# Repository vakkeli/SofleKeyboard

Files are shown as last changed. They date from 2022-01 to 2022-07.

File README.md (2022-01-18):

# Sofle Keyboard Vakkeli fork

Own version off the great keyboard. Added 7th column to better support ISO and Nordic layout. Will be updating this readme. PCB is in prototype production at this point. Hopefully adding 3D printed plates, case and models for them.

# Original Sofle Keyboard

Sofle is 6×4+5 keys column-staggered split keyboard with encoder support. Based on [Lily58](https://github.com/kata0510/Lily58), [Corne](https://github.com/foostan/crkbd) and [Helix](https://github.com/MakotoKurauchi/helix) keyboards.

**[For more information and documentation visit https://josefadamcik.github.io/SofleKeyboard/](https://josefadamcik.github.io/SofleKeyboard/)**

SofleKeyboard was created by [Josef Adamcik](https://josef-adamcik.cz/). The motivation and process is covered in following blog-post: [Let me introduce you SofleKeyboard - a split keyboard based on Lily58 and Crkbd](https://josef-adamcik.cz/electronics/let-me-introduce-you-sofle-keyboard-split-keyboard-based-on-lily58.html)

Sofle RGB was contributed by [Dane Evans](https://github.com/DaneEvans).

## Firmware

Sofle uses [QMK firmware](https://qmk.fm/)

## Default layout

Default layout for SofleKeyboard

## Images of keyboard

SofleKeyboard

SofleKeyboard Choc

SofleKeyboard PCB

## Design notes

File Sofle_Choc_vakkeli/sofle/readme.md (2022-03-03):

# Sofle Keyboard

SofleKeyboard version 1

Sofle is 6×4+5 keys column-staggered split keyboard. Based on Lily58, Corne and Helix keyboards.

More details about the keyboard on my blog: [Let me introduce you SofleKeyboard - a split keyboard based on Lily58 and Crkbd](https://josef-adamcik.cz/electronics/let-me-introduce-you-sofle-keyboard-split-keyboard-based-on-lily58.html)

The current (temporary) build guide and a build log is available here: [SofleKeyboard build log/guide](https://josef-adamcik.cz/electronics/soflekeyboard-build-log-and-build-guide.html)

* Keyboard Maintainer: [Josef Adamcik](https://josef-adamcik.cz) [Twitter:@josefadamcik](https://twitter.com/josefadamcik)  
* Hardware Supported: SofleKeyboard PCB, ProMicro  
* Hardware Availability: [PCB & Case Data](https://github.com/josefadamcik/SofleKeyboard)

Make example for this keyboard (after setting up your build environment):

    make sofle:default

Flash the default keymap: 

    make sofle:default:avrdude

Press reset button on he keyboard when asked.

Disconnect the first half, connect the second one and repeat the process.

See the [build environment setup](https://docs.qmk.fm/#/getting_started_build_tools) and the [make instructions](https://docs.qmk.fm/#/getting_started_make_guide) for more information. Brand new to QMK? Start with our [Complete Newbs Guide](https://docs.qmk.fm/#/newbs).

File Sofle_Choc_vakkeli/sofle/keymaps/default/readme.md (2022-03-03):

SofleKeyboard default keymap
SofleKeyboard adjust layer

# Default keymap for Sofle Keyboard

Layout in [Keyboard Layout Editor](http://www.keyboard-layout-editor.com/#/gists/76efb423a46cbbea75465cb468eef7ff) and [adjust layer](http://www.keyboard-layout-editor.com/#/gists/4bcf66f922cfd54da20ba04905d56bd4)

Features:

- Symmetric modifiers (CMD/Super, Alt/Opt, Ctrl, Shift)
- Various modes, can be switched (using Adjust layer and the selected one is stored in EEPROM.
- Modes for Qwerty and Colemak support
- Modes for Mac vs Linux/Win support -> different order of modifiers and different action shortcuts on the "UPPER" layer (the red one in the image). Designed to simplify transtions when switching between operating systems often.
- The OLED on master half shows selected mode and caps lock state and is rotated.
- Left encoder controls volume up/down/mute. Right encoder PGUP/PGDOWN.

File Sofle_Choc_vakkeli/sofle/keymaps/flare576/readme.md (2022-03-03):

Flare576 Keycaps
Flare576 Chord Guide

# Flare576's keymap for Sofle Keyboard

[Layout](http://www.keyboard-layout-editor.com/#/gists/fb8b42a6156458e20ca421a6f80cec48) and [Chord Mapping](http://www.keyboard-layout-editor.com/#/gists/884e3bc833cdf80fed9337ffee93a500) in Keyboard Layout Manager

Features:

- WASD -> ESDF Gaming layer
- Mouse/Arrow Keys Layer with **amazing** rates
- Tap/Hold keys for `=/+`/`SHIFT`, `TAB`/`ALT`
- Bracket layer with Fn Keys
- Right-hand primary OLED
  * Mode logo
  * Mode title
  * Luna WPM indicator
- Left-hand secondary OLED scrolling logo marquee
- Left encoder controls volume up/down/mute. Right encoder PGUP/PGDOWN/Home.

See [My Sofle Project](https://github.com/flare576/sofle) for more details

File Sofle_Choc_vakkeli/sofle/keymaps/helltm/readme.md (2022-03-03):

Luna - The QMK Keyboard Pet (https://www.youtube.com/watch?v=HgIQRazCAjo)

# Personal keymap for Sofle Keyboard rev1

Features:

- Modes for Qwerty and Games support. Games swaps enter and space to play FPS games and adds directional arrows.
- Modified Qwerty layout to allow usage without hidden layers (for the most).
- The OLED on master half shows selected OS, Layer and caps lock state.
- The secondary display shows a logo and the wpm counter.
- Left encoder controls arrow left/right. Right encoder arrow up/down.
- Holding shift changes the encoders to next/previous and volup/voldown respectively.
- Press the encoders to play/pause and mute.
- Smart Backspace (shift + backspace to delete)
- Single Layer button (press to Lower, shift + press to change mode)
- **Features Luna, your keyboard pet!**

#Luna, the keyboard pet

Features:
- Luna reacts to your wpm counter
    - under 10 wpm she sits
    - between 10 and 40 wpm she walks
    - over 40 wpm she runs
- She will move sneakily if you hold down Ctrl
- Will bark at people on the internet if you activate Caps Lock!
- Luna jumps every time you hit Space

Learn how to adopt a keyboard pet here
https://www.youtube.com/watch?v=HgIQRazCAjo

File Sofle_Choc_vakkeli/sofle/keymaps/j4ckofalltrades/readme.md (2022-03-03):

SofleKeyboard custom keymap

# Via-compatible custom keymap for Sofle

Modified version of default Via-compatible keymap with focus on adding a standard navigation cluster layer plus some
Vim-inspired features e.g. soft escape (Esc when held, Ctrl when tapped), using 'h', 'j', 'k', 'l' as arrow keys.

## Layout

View in [Keyboard Layout Editor](http://www.keyboard-layout-editor.com/#/gists/a1f6519e723ad81ca151741b53a28b80)

## Features

- Via support
- Mode for soft escape (`Esc` when tapped, `Ctrl` when held) 
- Vim-style navigation (`h` `j` `k` `l` as arrow keys)
- Mode for standard navigation cluster
- Toggling between layers when encoders are pressed
- Left encoder controls `VOLUP`/`VOLDOWN`. Right encoder `PGUP`/`PGDN`.

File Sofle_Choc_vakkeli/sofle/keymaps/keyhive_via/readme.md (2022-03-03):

# Only compatible with sofle/keyhive firmware which adds an extra column of keys for encoder mapping.

SofleKeyboard version 2.1 RGB Keyhive

# Configuring VIA / Vial App

This firmware will not auto-recognize until [PR #1060](https://github.com/the-via/keyboards/pull/1060) is accepted to the VIA keyboard database. For now you must install the new layout:

1. Download [keyhive_sofle_rgb.json](https://raw.githubusercontent.com/the-via/keyboards/48372baae5ab451d752988121fa4f1dd47b2c1ce/src/sofle/keyhive_sofle_rgb.json).
2. In the VIA app, select `File > Import Keymap` from the menu.
3. Open the file you just downloaded.

**You'll have to do this every time you use VIA or Vial until the PR is accepted.**

# Using with VIA
* The default layouts should be loaded automatically.
* Layouts can be backed up in VIA in the SAVE+LOAD section.
* It is a good idea to Save Current Layout after you decide on your mapping.

# Custom Features:

### Rotary Encoder and VIA Features:
* Fully remappable. Left encoder controls volume up/down/mute. Right encoder PGUP/PGDOWN.
* Allows for live remapping of per-layer rotary encoder functions in VIA.
* VIA support with **keyhive_via** keymap.

# Compiling

Make example for this keyboard (after setting up your build environment):

    make sofle/keyhive:keyhive_via

## Flashing

Flash using the correct command below (or use QMK Toolbox). These commands can be mixed if, for example, you have an Elite C on the left and a pro micro on the right.

Press reset button on the keyboard when asked.

Disconnect the first half, connect the second one and repeat the process.

    # for Pro Micro-based builds
    make sofle/keyhive:keyhive_via:avrdude-split-left
    make sofle/keyhive:keyhive_via:avrdude-split-right

    # for Elite C or DFU bootloader builds
    make sofle/keyhive:keyhive_via:dfu-split-left
    make sofle/keyhive:keyhive_via:dfu-split-right

See the [build environment setup](https://docs.qmk.fm/#/getting_started_build_tools) and the [make instructions](https://docs.qmk.fm/#/getting_started_make_guide) for more information. Brand new to QMK? Start with our [Complete Newbs Guide](https://docs.qmk.fm/#/newbs).

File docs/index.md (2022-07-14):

---
layout: default
---

SofleKeyboard

Sofle is 6×4+5 keys column-staggered split keyboard with encoder support. Based on [Lily58](https://github.com/kata0510/Lily58), [Corne](https://github.com/foostan/crkbd) and [Helix](https://github.com/MakotoKurauchi/helix) keyboards. SofleKeyboard version 1 and 2 were created by [Josef Adamcik](https://josef-adamcik.cz/). Sofle RGB was contributed by [Dane Evans](https://github.com/DaneEvans).

[Build guide is available here]({{ baseurl }}/SofleKeyboard/build_guide.html).

If you are interested in building the board and don't want to bother with KiCad, the gerber files are available in [releases](https://github.com/josefadamcik/SofleKeyboard/releases) or as [zip files in github repository](https://github.com/josefadamcik/SofleKeyboard/tree/master/Gerbers)

## Versions 

### Version 1

SofleKeyboard v1

The first version is mostly a modification of Lilly58 Pro. Motivation and detailed information is covered in the following blog-post: [Let me introduce you SofleKeyboard - a split keyboard based on Lily58 and Crkbd](https://josef-adamcik.cz/electronics/let-me-introduce-you-sofle-keyboard-split-keyboard-based-on-lily58.html). 

There were several group buys and PCBs or kits were available through several sellers. 

[Build guide is available here]({{ baseurl }}/SofleKeyboard/build_guide.html).

### Version 2

SofleKeyboard v1 and v2

Changes a stagger of columns and position of the bottom row a bit. The whole board was rerouted, shape changed slightly. Below version 1 in yellow, version 2 in blue.

SofleKeyboard v1/v2 layout comparison

A few experiments were made:

- A differently mounted micro-controllers with staggered holes.
- Placement of components around pro micros were also changed.
- Support for low profile Kailh Choc switches was dropped.

Those changes were experiments and I have been planning to reverse them and/or tweak them more. Details in the following blog-post: [Sofle Keyboard evolution: slow and not really steady](https://josef-adamcik.cz/electronics/soflekeyboard-evolving.html). 

Since the development was not moving forward for several months and there were many people interested in the new layouts (including group buys and vendors willing to sell kits), it was decided to release it in the current state as the version 2. Only one obvious problem was fixed (a too small size of a cut-out for encoder in the top plate).

[Build guide is available here]({{ baseurl }}/SofleKeyboard/build_guide.html).

### RGB

**&#9888; If you bought Sofle RGB from Keyhive, see the disclamer below, please.**

SofleKeyboard RGB

Sofle RGB was contributed by [Dane Evans](https://github.com/DaneEvans).

The Sofle RGB is a copy of the Sofle v2 with the addition of up to 36 RGB LEDs per side. If you are just looking to try out that layout, and are using the cherry sockets only, then this will work for you. 

The original pro-micro pinout was rolled back and routing was redone.

The OLED placement and OLED cover plate holes have not changed, and a plate has been designed. 

[Build guide is available here]({{ baseurl }}/SofleKeyboard/build_guide_rgb.html).

###	&#9888; Keyhive RGB

One keyboard vendor - Keyhive - is selling their own fork of Sofle RGB. This version is **modified** in way that makes it **incompatible** with the firmware for the official designs. You have to use the firmware provided by the vendor and build guide provided by them as well. Please, don't report problems with the desing and or firmware to this repository. Their modification is not part of the repository and therefore we cannot fix the problems or help you. Contact the vendor instead. In the end, you are their client.

[Build guide is available here]({{ baseurl }}/SofleKeyboard/build_guide_rgb.html).

### Choc

Sofle Choc

The Sofle Choc is a variation of the Sofle with:

   - low-profile, Kailh Choc switches
   - hotswap sockets
   - per-key RGB
   - thin, 15mm from desktop to top of keycaps
   - Sofle RGB switch layout with pinky stagger in between v1 and v2

The Sofle Choc was contributed by [Brian Low](https://github.com/brianlow) and based on the excellent Sofle RGB by [Dane Evans](https://github.com/DaneEvans).

[Build guide is available here]({{ baseurl }}/SofleKeyboard/build_guide_choc.html).

## Modifications

- [Sofle V2 with RJ12 instead of TRRS](https://gitlab.com/LayeredRx/Sofle_V2_Rj12/) by Layered RX

## License

- Hardware source files are licensed under MIT license.
- The documentation (both on [josefadamcik.github.io/SofleKeyboard/](https://josefadamcik.github.io/SofleKeyboard/) and [https://josef-adamcik.cz/](https://josef-adamcik.cz/)) is licensed under [Creative Commons Attribution 4.0 International (CC BY 4.0)](https://creativecommons.org/licenses/by/4.0/) license. This includes all photos and images in this repository and on the website.
- Firmware is part of QMK firmware and has the same licence (GPL v2)

## Firmware 

Sofle uses [QMK firmware](https://qmk.fm/)

See the [build environment setup](https://docs.qmk.fm/#/getting_started_build_tools) and the [make instructions](https://docs.qmk.fm/#/getting_started_make_guide) for more information. Brand new to QMK? Start with our [Complete Newbs Guide](https://docs.qmk.fm/#/newbs).

Make example for this keyboard (after setting up your build environment):

    make sofle:default

Flash the default keymap: 

    make sofle:default:avrdude

Press reset button on he keyboard when asked.

Disconnect the first half, connect the second one and repeat the process.

You can also use [QMK configurator](https://config.qmk.fm/#/sofle/rev1/LAYOUT) but beware, it does not support rotary encoders yet.

## Default layout 

Default layout for SofleKeyboard

## Gallery

Version 1 at the top, version 2 at the bottom:

SofleKeyboard

### Version 1

SofleKeyboard

SofleKeyboard Choc

SofleKeyboard PCB

### RGB

SofleRGBKeyboard

SofleRGBKeyboard

SofleRGBKeyboard PCB

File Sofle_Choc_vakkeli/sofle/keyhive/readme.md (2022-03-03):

# Keyhive Sofle Keyboard

SofleKeyboard version 2.1 RGB Keyhive

Sofle is 6×4+5 keys column-staggered split keyboard. Based on Lily58, Corne and Helix keyboards.

For details about the keyboard design, refer to Josef's blog: [Sofle Keyboard - a split keyboard based on Lily58 and Crkbd](https://josef-adamcik.cz/electronics/let-me-introduce-you-sofle-keyboard-split-keyboard-based-on-lily58.html)

Build guide: [Keyhive Sofle RGB build guide](https://github.com/keyhive/build_guides/blob/master/docs/keyboards/sofle-rgb.md)

* Keyboard Maintainer: [Winder](https://github.com/winder)
* Hardware Supported: Keyhive Sofle RGB, ProMicro / Elite-C
* Hardware Availability: [Keyhive](https://keyhive.xyz/shop/sofle)

### Acknowledgements

* Solartempest - the image on this page and most of the code is either copied directly or inspired by their fork. [Solartempest's fork.](https://github.com/solartempest/qmk_firmware/tree/master/keyboards/solartempest/sofle).
* [Keyhive fork](https://github.com/keyhive/qmk_firmware) defined all of the board settings.

# Supported Keymaps

The keyhive schematic has been slightly modified compared to the open source sofle and not all keymaps are compatible.

* **default**: Basic functionality, no rgb, no VIA.
* [keyhive_via](../keymaps/keyhive_via/readme.md) - Includes rgblighting and special support for remapping encoders with VIA.
* **Other**: may work but backwards compatibility is not guaranteed or tested.

# VIA Support
As of 1.3.1, the VIA tool does not support Keyhive/Sofle V2 out of the box.
See [keyhive_via](../keymaps/keyhive_via/readme.md) for details about configuring and using VIA.

# Compiling

Make example for this keyboard (after setting up your build environment):

    make sofle/keyhive:default

## Flashing

Flash using the correct command below (or use QMK Toolbox). These commands can be mixed if, for example, you have an Elite C on the left and a pro micro on the right.

Press reset button on the keyboard when asked.

Disconnect the first half, connect the second one and repeat the process.

    # for Pro Micro-based builds
    make sofle/keyhive:default:avrdude-split-left
    make sofle/keyhive:default:avrdude-split-right

    # for Elite C or DFU bootloader builds
    make sofle/keyhive:default:dfu-split-left
    make sofle/keyhive:default:dfu-split-right

See the [build environment setup](https://docs.qmk.fm/#/getting_started_build_tools) and the [make instructions](https://docs.qmk.fm/#/getting_started_make_guide) for more information. Brand new to QMK? Start with our [Complete Newbs Guide](https://docs.qmk.fm/#/newbs).

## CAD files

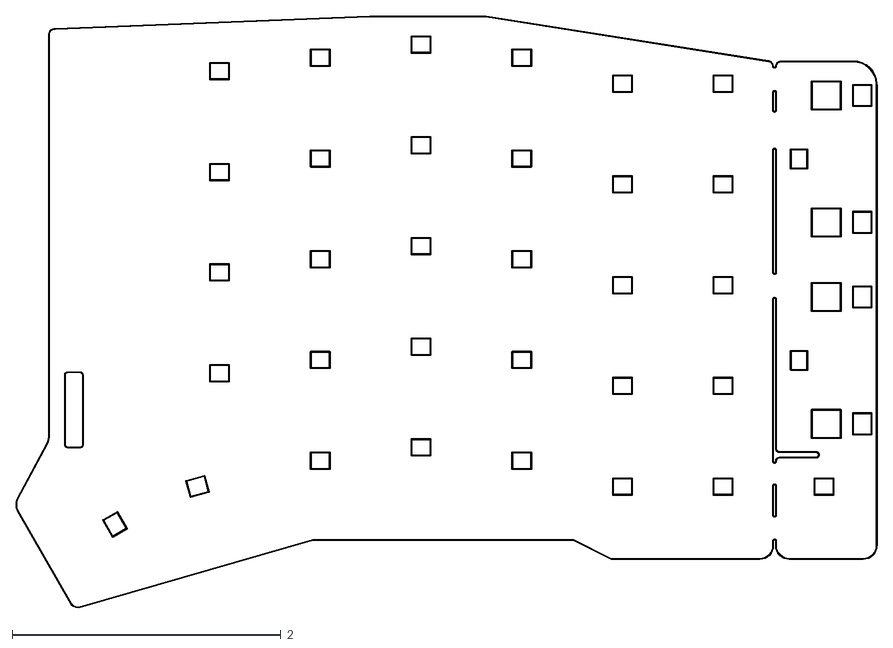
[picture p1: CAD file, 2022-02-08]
Sofle_Choc_vakkeli/gerber/SofleKeyboard-Edge_Cuts.dxf
6.41 x 4.40

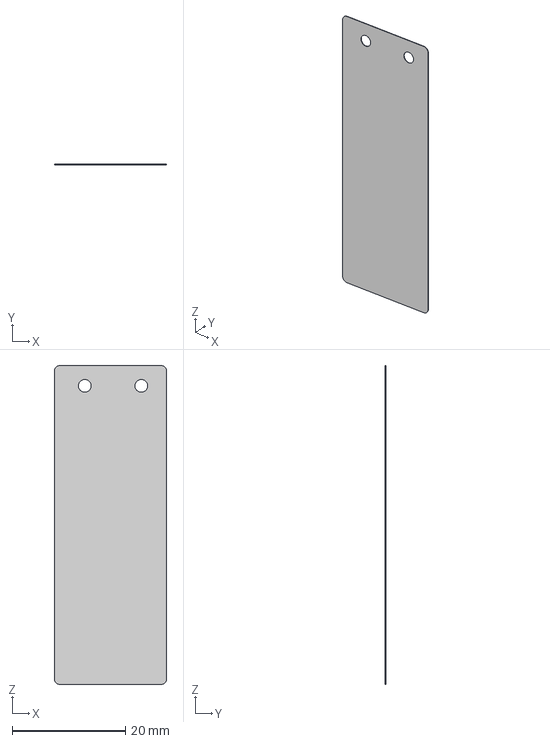
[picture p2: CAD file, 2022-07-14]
Sofle_v2/Case/sofle_v2_oled_cover_0.1.step
19.9 x 0.1 x 56.5 mm

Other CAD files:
Sofle_Choc_vakkeli/gerber/SofleKeyboard-B_Mask.dxf
Sofle_Choc_vakkeli/gerber/SofleKeyboard-B_SilkS.dxf
Sofle_Choc_vakkeli/gerber/SofleKeyboard-F_Mask.dxf
Sofle_Choc_vakkeli/gerber/SofleKeyboard-F_SilkS.dxf
Sofle_v2/Case/sofle_v2_oled_cover_0.1.dxf
Sofle_v2/Case/sofle_v2_oled_cover_0.1.f3d

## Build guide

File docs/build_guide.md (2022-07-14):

---
layout: default
title: Sofle Keyboard - build guide (v1/v2)
---

This guide suits both version **V1** and **V2** of the standard (**non-RGB**) Sofle Keyboard. Most of the photos are for v1 and the differences are explained in the text as needed.

The **RGB** version has [dedicated build guide][rgbbuildguide].

The **Choc** version has [dedicated build guide][chocbuildguide].

If you don't have all the necessary parts, please read about [how to source the parts][sourcing].

## Bill of materials

The following is needed to build the keyboard. You can find [links for the most of the components in the sourcing parts section][sourcing].

SofleKeyboard parts

- **2 PCBs** (see [sourcing][sourcing])
- **2 top plates**, **2 bottom plates** for a sandvich-case build. (see [sourcing][sourcing])
- **58 keyboard switch sockets by Kailh**. The PCB supports either sockets for traditional MX switches or sockets for Kailh Choc switches. **Note that version 2 supports only MX.** They are available on Aliexpress, KBDFans and others. 
- **58 keyboard switches** of your preference, either MX or [Kailh Choc][choc]. Just make sure you have matching sockets for them. **Note that version 2 supports only MX**.
- **58 keycaps**. You can use either all in `1u` size but it looks nicer with two `1.5u` for the thumb keys.
- **58 diodes  1N4148W**. They are surface mount diodes in SOD123 package.
- **2 TRRS connectors**. The same type which is used for Corne, Lily58 etc. Technically even TRS should work[^1] if you stick to (default) serial communication. 
- **2 tactile buttons** through-hole, 2 pins. Technically optional: you can use metal tweezers whenever you need to reset the microcontroller. There's also a reset key on default layout so as long as you have firmware flashed and working you shouldn't need reset button on the board. 
- **1 TRRS cable**. TRS should work[^1] if you stick with Serial. 
- **10 (+4) M2 spacers**. 10 are going to hold the bottom and the top together. Their height depends on which switches you use. A build guide Lily58 Pro suggests `4mm` for Choc and `7mm` for MX. I was not able to get `7mm`, but `6mm` worked well for me with MX switches. I used brass ones but you can also buy nicer from anodised aluminium. Another 4 would be needed to hold transparent OLED cover but even though there are mounting holes in the PCB.
- **20 (+8) M2 screws**. 20 are going to hold the boards together (via spacers). I used some I had in my stock so I am not going to tell you exact length. But they need to be long enough to fix a `1.6mm` thick PCB to the spacer and short enough so two of them can fit in one spacer (might be trickier with 4mm spacers for Choc switches)
- **8 - 10 adhesive rubber feet**. They are really important, trust me.
- **2 ssd1306 128x32 OLED display module**. Very common everywhere. 
- **2 OLED covers** Optional. OLED cover should be cut from transparent acrylic. Source file for [version 1 is avalalble in the repostiory](https://github.com/josefadamcik/SofleKeyboard/tree/master/Sofle_v1/Case). There is no OLED cover for version 2 available yet.
- **2 Rotary encoders EC11**, optional. So far I have used only one but 2 are supported. If you are not sure take EC11E. Some other variants (EC11K) may have some additional plastic pins for and require mounting holes for them (which are not included on the PCB).
- **A matching knob** for each encoder. 
- **2 Pro Micro**board or clone. With 2x12 pins and ATmega32U4 microcontroller. Just make sure you **don't** buy something like Arduino Micro (a different pinout) or Arduino Mini (different microcontroller). You could also use Elite-C which basically Pro Micro with USB-C.
- **4x12 pin header (and optionally socket)** for Pro Micros. There are several ways how to mount Pro Micros to the board. Either the male PIN headers you most likely got with the board from the supplier could be used to solder it directly to the board. Build guides for Helix, Corne and Lily58 suggest [those spring pin headers][springpinheader] which are very compact and give you non-permanent connection (you can remove or replace Pro Micros). Another possible approach [is described at splitkb.com][promicrosocketing].
- **2x4 pin header (and optionally socket)** for OLEDs. I have used the most common 1x4 female pin sockets which are quite tall but they also fit the height of ProMicro with the sockets I have used. Unfortunately, the pin headers on my OLED modules (again those very common square male headers you would get with the modules) are loose in the sockets. It works but it's fiddly. I'll have to find a better solution.
- **Micro USB Cable** to connect the keyboard to a computer.

SofleKeyboard parts 2

That's it. There are no RGB LEDs on the board. But if you really need underglow it is be possible to connect an RGB LED strip since there are 3 pads (VCC, GND and data) on the board. You would need to add support to the firmware on your own.

## Tools and materials

- soldering iron
- solder 
- good tweezers
- masking tape
- isopropyl-alcohol for cleaning 
- screwdriver

## Warnings and disclaimers

- Think twice, solder once. Desoldering is frustrating and it's easy to mess up things.
- Don't connect or disconnect the TRRS cable when the keyboard is powered. It may short out. Always disconnect the USB cable first.
- Be gentle with the USB on your microcontroller. They are easy to break.
- Keep in mind that this is a prototype of a DIY keyboard. It's not a polished product.

## Steps

### Prepare

Step 1

Both sides of the keyboard ready. The front sides marked by pieces of tape in order to remember which side is which.

### Components on the backside 

Step 2

Starting with the diodes. They belong to the backside of the PCB. Make sure you have orientation right - they are all oriented to the same side. The end with the thin line is Cathode (-) and it should go in the direction of the "arrow" symbol on the PCB.

Step 3

Sockets for switches belong again on the back side, the same side as diodes. Make sure they are flush with PCB. Watch the markings on the silkscreen which show the correct orientation.

### Components on the front side

Step 4

Button and TRRS sockets belong to the top. Use a piece of tape to fix them and apply solder from the bottom side.

Step 5

This is how the right half should look from the top.

### Pro Micro and displays

Step 6

Bridge 4 jumper pads on the top side. They are necessary for OLED support and if you don't socket you Pro Micro you will not be able to do it later.

Step 7

Prepare the Pro Micro. There are several ways how to do it. I have used rounded pin headers. A bit more information about [socketing of Pro Micro is on the sourcing parts page][sourcing]. 

**Keep in mind the orientation**: 

Pro micro orienation

Version 1: the Pro Micro board should be mounted "bottom-up". Its clean side should be at the top, visible. The side with chips and other electronics should be at the bottom facing the main PCB. 

Version 2: The left side as for version 1. The right half has the pro micro mounted up-side up so it's mounted differently on each half. 

Step 8

And corresponding sockets (if used) on the front side of the board. Version 1: Make sure you insert them into the holes which are marked by the rectangles. Version 2: there's only one option so it is straightforward.

Step 9

Add socket for OLED display. Keep in mind height of your Pro Micro which may be different based on if/which socket's you have used for Pro Micro. Check everything before soldering.

Step 10

This is how the backside (bottom) should look at this stage.

### First test

Step 11

Now it is already possible to connect the ProMicro and OLED display to the board, flash the firmware and check if all keys work using a piece of wire or tweezers.

### Rotary encoders

Step 12

Both halves assembled, a rotary encoder can be added on both, one or none. I have also cleaned flux residue from the back side using some isopropyl alcohol, cotton buds and paper towels.

### Keyboard switches and plates

Step 14

Snap first switches into corners.

Step 15

Mount the stand-offs to the top plate.

Step 16

Carefully snap the first switches to the sockets. Be careful so you don't bend their contacts. Add more.

Step 17

Until they are all in place.

Step 18

Double-check the bottom. You should see all the contacts in sockets.

Step 19

And mount the bottom plate.

Step 20

Completed half of the keyboard waiting for keycaps.

### Finishing touches

Step 21

Put at least 4 adhesive rubber feet in the corners so the keyboard is not moving when you type.

## Warnings and disclaimers

- Don't connect or disconnect the TRRS cable when the keyboard is powered. It may short out. Always disconnect the USB cable first.
- Be gentle with micro USB ports on your microcontrollers. They are easy to break.
- Keep in mind that this is a prototype of a DIY keyboard. It's not a polished product.

## Firmware and programming

Sofle keyboard uses [QMK Firmware][qmk_firmware] and support for the board is part of the main QMK repository. There's also a basic support in [QMK Configurator][qmk_configurator] but there's no default layout yet and encoders are not supported.

Suggested approach is to build the firmware yourself. You should be familiar with QMK and be able to make it work on your local environment. If not, please [follow the instructions in the documentation][qmkintro].

- Make sure your QMK environment [is setup][qmkintro].
- Make sure halves are not connected together with TRRS cable.
- Connect one half to USB, flash the firmware (always follow the actuall instructions in the QMK documentation! The command might look something like this: `qmk flash -kb sofle/rev1 -km default`). Use the reset button to reset the keyboard when you are asked to in console. 
- Connect the second half and flash it in the same way as the previous one.
- Disconnect the USB cable. Connect both halves together with TRRS cable.
- Connect USB cable to the **left** side[^2]. 
- Enjoy SofleKeyboard!

## Troubleshooting

### Elite-C v3.0

Elite-C v3.0 had problems when used with split boards (on both halves). Those are fixed in version 3.1. For v3.0 add `#define SPLIT_USB_DETECT` to `config.h` file. I don't have Elite-C so this is untested, but should work.

### Typing lag when used without OLED 

If you chose to not use OLED for both halves you should disable support for oled (set `OLED_DRIVER_ENABLE` to `no` in `keymaps/defualt/rules.mk`).

If you don't use OLED only on one half you are need to do **one** of the following to fix the lag:

- Solder pull-up resistors (4k7) to the PCB (R1, R2) without OLED.
- Use a workaround explained [in this issue][nooledlag].
- Stop using OLED completely and turn it off as described above.

## Modifications

### Inverted silkscreen

If you fancy an [inverted silkscreen there's a great guide available](https://github.com/josefadamcik/SofleKeyboard/issues/3#issuecomment-683192038).

## Links

- [Github with KiCad projects][soflegithub]
- [Layout in KeyboardLayout editor][soflelayout]
- [QMK Firmware][qmk_firmware]
- [QMK Configurator][qmk_configurator]

## Footnotes

[^1]: Serial is the default behaviour. If serial is used, you don't need TRRS cable (4 contacts, used for headphones with a microphone) but just TRS (stereo audio jack). 
[^2]: This can be changed, look for [setting handednesss][qmkhandedness] in QMK documentation.
[^3]: There was a design issue where the cutout for the encoder is big enough only for the base of the encoder but not for its legs. That is perfectly ok when you build the board with MX switches since the plate sits above the legs. But for low profile Kailh Choc switches there's no longer any gap between plates. If you have unfixed plate (the problem was fixed in v1.1.) and wish to use an encoder, you'll need to file off a bit of PCB material to get the legs of encoder through (see the guide above).

[layoutarticle]: <https://josef-adamcik.cz/electronics/in-search-of-the-best-custom-keyboard-layout.html> "In search of the best custom keyboard layout"
[introductionarticle]: <https://josef-adamcik.cz/electronics/let-me-introduce-you-sofle-keyboard-split-keyboard-based-on-lily58.html> "Let me introduce you SofleKeyboard - a split keyboard based on Lily58 and Crkbd"
[soflelayout]: http://www.keyboard-layout-editor.com/#/gists/76efb423a46cbbea75465cb468eef7ff "Sofle Keyboard layout at keyboard-layout-editor.com"
[soflegerber]: https://github.com/josefadamcik/SofleKeyboard/releases "SofleKeyboard - gerber files"
[qmk_firmware]: https://github.com/qmk/qmk_firmware/ "QMK firmware"
{:target="_blank"}
[qmk_configurator]: https://config.qmk.fm/#/sofle/rev1/LAYOUT "QMK configurator"
{:target="_blank"}
[springpinheader]: <https://yushakobo.jp/shop/a01mc-00/> "Spring pin headers - Japaneese"
{:target="_blank"}
[qmkprotonc]: https://qmk.fm/proton-c/ "QMK Proton-C"
{:target="_blank"}
[promicrosocketing]: <https://docs.splitkb.com/hc/en-us/articles/360011263059> "How do I socket a microcontroller? by splitkb.com"
{:target="_blank"}
[qmkintro]: <https://beta.docs.qmk.fm/tutorial/newbs_getting_started> "QMK getting started"
{:target="_blank"}
[qmkhandedness]: <https://docs.qmk.fm/#/feature_split_keyboard?id=setting-handedness> "QMK firmware - setting handedness"
{:target="_blank"}
[manufacturingproblems]: https://josef-adamcik.cz/electronics/corne-keyboard-build-log.html#manufacturing-at-jlcpcb---update-27112019 "Possible problems when manufacturing top plate for Corne"
[nooledlag]: https://github.com/qmk/qmk_firmware/issues/7522 "No OLED lag bug"
[soflegithub]: https://github.com/josefadamcik/SofleKeyboard "SofleKeyboard - KiCad project on Github.com"
[sourcing]: <{{ site.baseurl }}/sourcing_parts.html> "Sourcing parts"
[rgbbuildguide]: <{{ site.baseurl }}/build_guide_rgb.html> "Sofle RGB build guide"
[chocbuildguide]: <{{ site.baseurl }}/build_guide_choc.html> "Sofle Choc build guide"

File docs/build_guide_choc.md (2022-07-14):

---
layout: default
title: Sofle Keyboard - build guide (Choc)
---

Keyboard
Keyboard Side View

The Sofle Choc is a variation of the Sofle with:

   - low-profile, Kailh Choc switches
   - hotswap sockets
   - per-key RGB
   - thin, 15mm from desktop to top of keycaps
   - Sofle RGB switch layout with pinky stagger in between v1 and v2

This version supports [Kailh Choc v1 switches](https://deskthority.net/wiki/Kailh_PG1350_series). Kailh hotswap sockets are required. Per-key RGB is optional and uses the relativey easy to solder SK6812 MINI-E LEDs.

The top plates are not compatible with Sofle v1, v2 or RGB versions. There is no bottom plate to minimize thickness.

The Sofle Choc was designed by [Brian Low](https://github.com/brianlow) and based on the excellent Sofle RGB by [Dane Evans](https://github.com/DaneEvans) which was based on the original Sofle v2 by [Josef Adamčík](https://github.com/josefadamcik).

## Updated Build Guide and Kits

I am maintaining a newer version of the build guide and usually have kits available at:

[http://choc.brianlow.com](http://choc.brianlow.com)

## Bill of materials

The following is needed to build the keyboard:

- **2 PCBs**. Send the zip from `/Gerbers/Choc_v2/choc-v2-gerber-pcb.zip` to a PCB fabrication service. The PCB should be 1.6mm thick [though 1.2mm may be better](https://github.com/josefadamcik/SofleKeyboard/issues/136#issuecomment-1045965676). Otherwise I used JLCPCB's default settings only customizing the PCB color. See [sourcing][sourcing].

- **2 top plates**. Send the zip `/Gerbers/Choc_v2/choc-v2-gerber-top.zip` to a PCB fabrication service. The top plate holds the switches in place. The top plate should be 1.2mm thick. Otherwise I used JLCPCB's default settings only customizing the PCB color. See [sourcing][sourcing].

- **2 Pro Micro** boards or clones. 5v, 2x12 pins, ATmega32U4 microcontroller. **Don't** buy the Arduino Micro (a different pinout) or Arduino Mini (different microcontroller). You could also use Elite-C which basically Pro Micro with USB-C.

- **4x 12 pin headers (and optional sockets)** for Pro Micros. There are several ways to mount Pro Micros to the board. The male pin headers you most likely got with the board can be used to solder it directly to the board. This makes it hard to replace the board if it fails. The micro-USB connector is known to tear off. I socketed the Pro Micro using the diode legs approach [described at splitkb.com][promicrosocketing] with two 12-pin female headers. This is the option descibed in the build guide here. Lastly, [these spring pin headers][springpinheader] are used on similar keyboards and should give a compact, non-permanent connection but have been out of stock for a long time.

- **58 Kailh Choc keyboard switches**. Must be [Kailh Choc v1 switches (PG1350)](https://deskthority.net/wiki/Kailh_PG1350_series) of any color. The `PG` prefix is often omitted. **Don't** buy [Kailh Choc v2](https://deskthority.net/wiki/Kailh_PG1353_series), [Kailh Mini Choc](https://deskthority.net/wiki/Kailh_PG1232_series) or [Cherry MX](https://deskthority.net/wiki/Cherry_MX).

- **58 Kailh Choc keyboard switch sockets**. Sockets are specific to the PG1350 switch. The PCB requires sockets. Switches cannot be soldered directly to the board.

- **58 keycaps**. You can use either all in `1u` size but it looks nicer with two `1.5u` for the thumb keys.

- **58 diodes 1N4148W**. Surface mount diodes in SOD123 package. Pick any common variation. I used `1N4148WTR` (Digi-Key 1655-1360-1-ND).

- **2 TRRS connectors**. The same type which is used for Corne, Lily58 etc. Technically even TRS should work if you stick to the default serial communication.

- **2 buttons** momentary, tactile, through-hole, 2 pins, I used one for DIP switches, 3x6x4.3mm. Technically optional: you can use metal tweezers whenever you need to reset the microcontroller.

- **1 TRRS cable**. TRS should work if you stick with the default serial communications.

- **8 - 10 silicone bumpers**. Used for feet to keep the keyboard from moving

- **Micro USB Cable** to connect the keyboard to a computer.

Optional components:

- **OLED/s**
  - **2 SSD1306 128x32 OLED display module**. 4-pin, I2C, 0.91". Very common.
  - **2x 4 pin header (and optionally socket)** for OLEDs. These came pre-soldered to the OLED unit. You can solder the OLED directly to the board. Ideally use a socket so you can replace and/or get at the ProMicro underneath. I found 4 pin female headers with half height (~4mm) insulation worked well
  - **2 OLED covers** This should be compatible with the Sofle RGB cover but have not verified

- **Rotary encoders**
  - **2 Rotary encoders EC11**. If you are not sure take EC11E. Some other variants (EC11K) may have some additional plastic pins for and require mounting holes for them which are not included on the PCB. Perfer short shaft. I used encoders with 10mm, D-shaped shaft and 30 positions from AliExpress. I also tried a high quality Bourns encoder (PEC11 series) but found it required a bit too much effort to twist.
  - **2 matching knobs** for each encoder. Make sure the knob matches the encoder's shaft diameter, depth and shape.
  - **2 diodes 1N4148W** the encoder shafts are pushable and can be used as configurable keys.

- **LEDs**
  - **58 SK6812 MINI-E RGB LEDs**. The LED body 3.2x2.8x1.7mm and with legs is 5.8x2.8. Avoid the non-MINI-E version without the legs. Purchase extra as they are delicate. I ended up replacing 6 during my build.

- **Resistors**
  - **2x 4.7kOhm through hole resistors** These only needed if you want to use the less common I2C communication protocol between halves. They are installed in the R1/R2 spots. I have not tested an I2C setup. The firmware on this page uses serial communication and does not require the resistors.

Components that are common on other Sofle variants but are **not** used on this Softle Choc: bottom plate, M2 spacers and screws.

## Tools and materials

- soldering iron and solder
- no-clean flux makes soldering easier
- solder wick or desoldering pump to correct mistakes
- good tweezers
- flush cutters to trim diode legs when socketing the ProMicro
- masking, kapton or electrical tape
- isopropyl-alcohol for cleaning
- screwdriver
- 1.5mm hex key for the set screw on the encoder knob
- mulitmeter for troubleshooting

## Steps

### Prepare

Make sure you know which side you are working on, and don't make two left hand sides by mistake. Stick a piece of tape on the front side of both PCBs to help remember.

This guide is written in the order I like to install components.

We will start with the components on the back, shortest to tallest:
  - diodes
  - LEDs
  - switch sockets

Then install the components on the front:
  - OLED jumpers
  - ProMicro & socket
  - OLED & socket
  - reset switch
  - TRRS connector
  - encoder

The order of assemby does not matter **except** for these 3 components because they stack on top of one another:
  1. the four OLED jumpers
  2. the Pro Micro
  3. the OLED screen

The build guides for the Sofle and Sofle RGB have some good tips and photos. However there are differences so use this page as your primary reference. In particular, use the ProMicro orientation described on this page.

### Switch Sockets and Diodes

Switch sockets and diodes

These components are placed on the back of the PCB.

Diodes must be oriented with the white band in the direction of the "arrow" symbol on the PCB. I typically tin one pad, place the diode on, apply the soldering iron to the diode leg until it melts the solder underneath and sinks flush with the PCB. Then come back and solder the other leg.

The sockets are the largest and easiest to solder. They are installed on the back of the PCB facing up towards the front of the PCB. Make sure they are flush with the PCB. Heat the metal connector, apply solder and look for the solder to wick down to the PCB. You want a solid joint since this may take some mechanical strain from switch installation and removal.

### The LEDs

LED

LEDs are placed on the back of the PCB. The lens should point up through the PCB so they shine into the bottom of the switch. One leg will have a diagonal cut. This cut leg should be aligned with the triangular marking on the PCB.

To solder: tin one pad, place the LED and hold using tweezers, apply heat to the leg until the solder melts and the LED is flush with the board. Now the remaining legs can be soldered without the component moving. The LEDs are sensitive to heat. Let the LED cool between soldering each leg. Use the lowest heat needed for your solder.

The LEDs are wired in one long chain. If a LED is not working, replace the LED and the LED preceeding it. Sometimes just the output of a LED is damaged. The full chain does not need to be installed if you want to test a partially built board.

LED

### OLED Jumpers

OLED Jumpers

Now we move to the front of the PCB.

The jumpers in the photo should be bridged if using an OLED dispay. The jumpers may not be accessible later in the build depending on how the Pro Micro is attached. Bridge the jumpers on the top side of the board, the same side the ProMicro will be mounted on.

### Pro Micro

Pro Micro

The Pro Micro is installed on the top of the board, upside down and in the marked holes.

* Top of the board: this is the side of the PCB opposite the diodes, LEDs and switch sockets
* Upside down: both Pro Micro components should face the PCB with the mostly plain back facing out
* Marked holes: there are two sets of holes in the PCB, use the holes with the rectangular outline on the top of the board

Double-check your work here. This step is hard to reverse if a mistake is made.

To install a socketed Pro Micro using the diode leg approach [from splitkb.com][promicrosocketing]:

  1. Install the 12-pin female headers on the top of the board in the outlined through holes. Use some tape to temporarily tack them in place. Flip the board over onto a flat, hard surface. While soldering the first pins, push down on the PCB to ensure the headers are perpendicular and fully seated.

  2. Flip the board upright again. Optionally place some tape over the sockets to protect against fusing parts together. Place the Pro Micro upside down on top. Push diodes though the Pro Micro holes, through the tape and seated into the socket below.

  3. Solder the legs to the Pro Micro. Snip off the legs above the Pro Micro.

If you ever need to remove the Pro Micro: do it by gently prying the board up in small increments, working your way around the board. Avoid pressure on the USB connector. The diode leags are quite weak and will usually bend if you pull the Pro Micro off in one action.

### OLED

Install the OLED so it overhangs the Pro Micro. I added electrican's tape to the bottom of the OLED module where it might contact the Pro Micro.

If you are socketing the OLED, install the 4 pin, half height female header on the top of the PCB. Then push the OLED pins into the socket. You may need to trim the OLED pins so the insulation on the female and male headers mate and the OLED sits just above the Pro Micro. The downside to socketing is the OLED isn't as secure in the half height socket. When turning the keyboard upside down I find the OLED will lever away from the Pro Micro somewhat.

### Solder misc components

Use tape to tack each component in place while flipping the board over to solder.

Solder the reset switch.

Solder the TRRS connector. You may need to bend the TRRS connector pins 90 degrees so they point down into the PCB. The R1 and R2 locations should remain empty.

Solder the encoder.

### Assemble

- Snap a few switches into the top plate, the corner switches work best

- Place the PCB on a flat surface. This will save some strain on the solder joints in the next step (though they should be able handle it).

- Carefully lower the top plate with switches on the main PCB and push into sockets. Ensure pins are aligned.

- Snap the remaining switches into the top plate pressing into the sockets.

- There are no standoff between the PCB and top plate

- Place the encoder knob on the shaft. Tighten the set screw with a hex key. A small screwdriver for glasses may do in a pinch.

- Optionally add oled covers

- Put at least 4 adhesive rubber feet in the corners so the keyboard is not moving when you type.

## Warnings and disclaimers

- Don't connect or disconnect the TRRS cable when the keyboard is powered. It may short out. Always disconnect the USB cable first.
- Be gentle with micro USB ports on your microcontrollers. They are easy to break.
- Keep in mind that this is a prototype of a DIY keyboard. It's not a polished product.

## Firmware and programming

The Sofle Choc uses [QMK Firmware][qmk_firmware]. Support is not in the main QMK repository [yet](https://github.com/qmk/qmk_firmware/pull/16736). Instead use the [brianlow/qmk_firmware](https://github.com/brianlow/qmk_firmware) fork.
Suggested approach is to build the firmware yourself. You should be familiar with QMK and be able to make it work on your local environment. If not, please [follow the instructions in the documentation][qmkintro]. Note QMK setup is fairly invasive (upgrade every homebrew package on your system) so you might want to consider the [QMK Docker image](https://beta.docs.qmk.fm/using-qmk/guides/development-environments/getting_started_docker) for compiling.

To flash:

- Clone [https://github.com/brianlow/qmk_firmware](https://github.com/brianlow/qmk_firmware)
- Switch to the `choc2` branch with `git checkout choc2`
- Make sure your QMK environment [is setup][qmkintro].
- Make sure halves are not connected together with TRRS cable.
- Connect one half to USB, flash the firmware (always follow the current instructions in the QMK documentation! The command might look something like this: `qmk flash -kb sofle_choc -km default`). Use the reset button to reset the keyboard when you are asked to in console. Some Pro Micros require double-clicking the reset button to enter bootloader mode.
- Connect the second half and flash it in the same way as the previous one.
- Disconnect the USB cable. Connect both halves together with TRRS cable.
- Connect USB cable to the **left** side.
- Enjoy SofleKeyboard!

There is also a firmware version that uses [VIA](https://caniusevia.com/). VIA allows you to quickly change your keymap without flashing or a QMK build environment. I highly recommend it for experimenting. There are few downsides:
- it doesn't support custom logic like a key for switching betwen Mac/Win
- the exporting/importing keymaps has some problems with some multi-chord keys though typically I don't find I need to export/import
- lighting configuration keys only seem to affect lighting on the master side. If you don't change lighting much, a workaround is to plug just the right side in to the computer, change the lighting then plug everrything back normally

To use the VIA firmware

- Clone https://github.com/brianlow/qmk_firmware
- Switch to the `choc-brian` branch with `git checkout choc-brian`
- When flashing use the `choc_brian` keymap: `qmk flash -kb sofle/rev1 -km choc-brian`
- Download the VIA app from https://caniusevia.com/, it should recognize the keyboard when it opens

## Troubleshooting

See the Sofle build guide.

## Links

- [Github with KiCad projects][soflegithub]
- [Layout in KeyboardLayout editor][soflechoclayout]
- [QMK Firmware][qmk_firmware]
- [QMK Configurator][qmk_configurator]

## Default layout

The default layout for the Sofle Choc is in the QMK fork and demonstrates some LED functions.

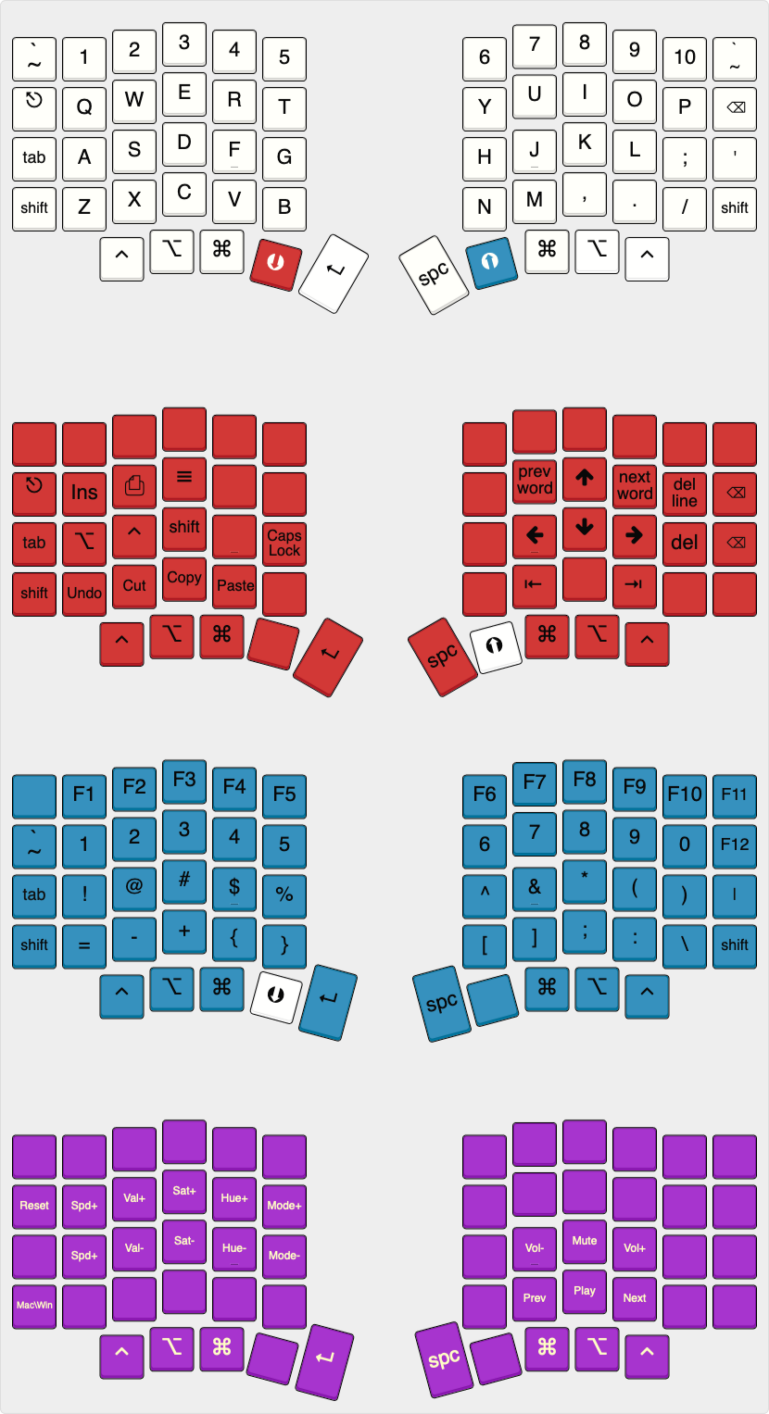
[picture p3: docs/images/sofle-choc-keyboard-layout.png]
Default layout for Sofle Choc Keyboard


## Images of keyboard

Keyboard Photo 1

Keyboard Photo 2

## Version History

* v2.1.1 - Top plate: moved the version label to less visible location, widened the area above the encoder. PCB version remains at v2.1
* v2.1 - First published version

## Footnotes
[layoutarticle]: <https://josef-adamcik.cz/electronics/in-search-of-the-best-custom-keyboard-layout.html> "In search of the best custom keyboard layout"
[introductionarticle]: <https://josef-adamcik.cz/electronics/let-me-introduce-you-sofle-keyboard-split-keyboard-based-on-lily58.html> "Let me introduce you SofleKeyboard - a split keyboard based on Lily58 and Crkbd"
[soflelayout]: http://www.keyboard-layout-editor.com/#/gists/76efb423a46cbbea75465cb468eef7ff "Sofle Keyboard layout at keyboard-layout-editor.com"
[soflechoclayout]: http://www.keyboard-layout-editor.com/#/gists/5604075ad16c10a8c634828c5911d2b6 "Sofle Choc Keyboard layout at keyboard-layout-editor.com"
[soflegerber]: https://github.com/josefadamcik/SofleKeyboard/releases "SofleKeyboard - gerber files"
[qmk_firmware]: https://github.com/qmk/qmk_firmware/ "QMK firmware"

[qmk_configurator]: https://config.qmk.fm/#/sofle/rev1/LAYOUT "QMK configurator"
[springpinheader]: <https://yushakobo.jp/shop/a01mc-00/> "Spring pin headers - Japanese"
[qmkprotonc]: https://qmk.fm/proton-c/ "QMK Proton-C"
[promicrosocketing]: <https://docs.splitkb.com/hc/en-us/articles/360011263059> "How do I socket a microcontroller? by splitkb.com"
[qmkintro]: <https://beta.docs.qmk.fm/newbs/newbs_getting_started> "QMK getting started"
[qmkhandedness]: <https://docs.qmk.fm/#/feature_split_keyboard?id=setting-handedness> "QMK firmware - setting handedness"
[manufacturingproblems]: https://josef-adamcik.cz/electronics/corne-keyboard-build-log.html#manufacturing-at-jlcpcb---update-27112019 "Possible problems when manufacturing top plate for Corne"
[nooledlag]: https://github.com/qmk/qmk_firmware/issues/7522 "No OLED lag bug"
[soflegithub]: https://github.com/josefadamcik/SofleKeyboard "SofleKeyboard - KiCad project on Github.com"
[sourcing]: <{{ site.baseurl }}/sourcing_parts.html> "Sourcing parts"

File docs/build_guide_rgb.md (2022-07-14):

---
layout: default
title: Sofle Keyboard - build guide (RGB)
---

The Sofle RGB is a copy of the Sofle V2 with the addition of up to 36 RGB leds per side. If you are just looking to try out that layout, and are using the cherry sockets only, then this will work for you. Please mind that the layout has slight modifications, mainly the pinkie stagger is less aggresive than for non-RGB Sofle V2.

This version rolls back the original pro-micro pinout (to the state it was for V1) and improves routing.

## This Build Guide

This build guide is based on a copy of the main [build guide][buildguide]. We suggest to revisit the main [build guide][buildguide] for general process and tips about technique. But this build guide is the main source of important details for your build - like Pro-Micro orientation, component placement etc.

**&#9888; Keyhive version: Pay attention, if you purchased Sofle RGB from Keyhive**

One keyboard vendor - Keyhive - is selling their own fork of Sofle RGB. This version is **modified** in way that makes it **incompatible** with the **firmware** for the official designs. Also this build guide no longer applies to their version. 

**&#9888; If you purchased their modified version, you have to use the firmware provided by the vendor and [the build guide provided by them as well][keyhivebuildguide].**

Please, don't report problems with the design by Keyhive and or firmware to the official Sofle Keyboard repository. Their modification is not part of the repository and therefore we can't fix any problems and we can't help with any problems you might have with the design. Contact the vendor instead. In the end, you are their client.

## Bill of materials

The following is needed to build the keyboard.

- **2 PCBs**, ** NOTE: ** There is an issue with the v2.0 boards. See the Troubleshooting section at the bottom of the page for further details if you were unlucky enough to get a board made with these files. 
- **2 top plates**, **2 bottom plates** for a sandwich-case build.

- **2 Pro Micro** board or clone. With 2x12 pins and ATmega32U4 microcontroller. Just make sure you **don't** buy something like Arduino Micro (a different pinout) or Arduino Mini (different microcontroller). You could also use Elite-C which basically Pro Micro with USB-C.
- **4x12 pin header (and optionally socket)** for Pro Micros. There are several ways how to mount Pro Micros to the board. Either the male PIN headers you most likely got with the board from the supplier could be used to solder it directly to the board. Build guides for Helix, Corne and Lily58 suggest [those spring pin headers][springpinheader] which are very compact and give you non-permanent connection (you can remove or replace Pro Micros). Another possible approach [is described at splitkb.com][promicrosocketing].

- **58 keyboard switch sockets by Kailh**. The PCB supports sockets for traditional MX switches. They are available on Aliexpress, KBDFans and others.
- **58 keyboard switches** of your preference, MX. Just make sure you have matching sockets for them.
- **58 keycaps**. You can use either all in `1u` size but it looks nicer with two `1.5u` for the thumb keys.
- **58 diodes  1N4148W**. They are surface mount diodes in SOD123 package.
- **2 TRRS connectors**. The same type which is used for Corne, Lily58 etc. Technically even TRS should work[^1] if you stick to (default) serial communication. 
- **2 tactile buttons** through-hole, 2 pins. Technically optional: you can use metal tweezers whenever you need to reset the microcontroller. There's also a reset key on default layout so as long as you have firmware flashed and working you shouldn't need reset button on the board. 
- **1 TRRS cable**. TRS should work if you stick with Serial. 
- **10 (+4) M2 spacers**. 10 are going to hold the bottom and the top together. Their height depends on which switches you use. A build guide Lily58 Pro suggests  `7mm` for MX. I was not able to get `7mm`, but `6mm` worked well for me with MX switches. I used brass ones but you can also buy nicer from anodised aluminium. 
- **20 (+8) M2 screws**. 20 are going to hold the boards together (via spacers). I used some I had in my stock so I am not going to tell you exact length. But they need to be long enough to fix a `1.6mm` thick PCB to the spacer and short enough so two of them can fit in one spacer (might be trickier with 4mm spacers for Choc switches)
- **8 - 10 adhesive rubber feet**. They are really important, trust me.
- **Micro USB Cable** to connect the keyboard to a computer.

**Optional**
- **OLED/s**
	- **2 ssd1306 128x32 OLED display module**. Very common everywhere. 
	- **2x 4 pin header (and optionally socket)** for OLEDs. I have used the most common 1x4 female pin sockets which are quite tall but they also fit the height of ProMicro with the sockets I have used. Unfortunately, the pin headers on my OLED modules (again those very common square male headers you would get with the modules) are loose in the sockets. It works but it's fiddly. I'll have to find a better solution.
	- **2 OLED cover** This is available in [the repository (oled_cover.svg)](https://github.com/josefadamcik/SofleKeyboard/tree/master/Sofle_RGB/Case/)
	
- **Rotary encoders**
	- **2 Rotary encoders EC11**, If you are not sure take EC11E. Some other variants (EC11K) may have some additional plastic pins for and require mounting holes for them (which are not included on the PCB).
	- **A matching knob** for each encoder. 
	
- **LEDs**
	- **SK6812 mini rgb leds (3.5mmx3.5mm size)** make sure that you get the style with irregular shaped pads that are flush to the led, and make very sure that you know what the pinout for your variant is. There are at least  2 common pinouts, thankfully just rotated 180 degrees, but for you the pin 1 marking may be on pin 3.
		- **2x forward facing layer indicator**
		- **12x rear facing drop lights**
		- **58x per key lights** 

## Tools and materials

- soldering iron
- solder 
- good tweezers
- masking tape
- isopropyl-alcohol for cleaning
- screwdriver

## Steps

### Prepare

Make sure you know which side you are working on, and don't make two left hand sides by mistake 

### The LEDs
SofleKeyboard

Work out what leds you wish to have, I have endeavoured  to provide plenty of flexibility, and all led configurations are available using the headers available. If you wish to experiment, use 2.54mm headers and jumpers. If you know what you want, use a solder bridge to enable the leds required.  
The traditional LED header is available, and can be used alone, or theoretically fed back in to one of the other headers if so desired. 

Make sure you know which way around your leds are, different brands have different pin 1 positions. Thankfully it appears that the pad pattern underneath is consistent, so use it. I recommend doing one LED and testing it before continuing. This unfortunately suggests soldering the micro on first, despite it making the back side harder to solder. A good alternative would be to use an existing keyboard with leds to inject the signal and power through the LED header.

#### LED pinouts

LED pinout from the crkbd build guide. I've found this to be the only consistent method

The above picture is from the crkbd guide shows pin 4 on the table (the table is viewed from the top of the LED). 

**The sofle RGB uses the following table, with the silkscreen marking at pin 1 (Dout)**

| pin | net | net | pin |
| --- | --- | --- | --- |
| 1 | Dout | Vcc | 4 | 
| 2 | Gnd  | Din | 3 | 

Using the base pattern is the only consistent pattern between at least two different models with different pin 1 definitions and markings.

The following two datasheet excerpts show two versions of the led with different numbering pattern. But shows the same layout and net labels on the bottom.

datasheet

**Soldering** 

The surface mount LEDs are easier to solder, and there are only 1+6 of them on each side, so are a good place to start if you aren't used to soldering them. Use a fairly low temperature (240c) and lots of flux. Place the led in position, heat one of the pads on the board for several seconds before moving the iron to touch the pin on the led , then add solder. Moving the iron back and forth from the pin can help to flow the solder under the LED, 

I have added a single LED to the top surface to act as a layer indicator, this is enabled by bridging 2-3 on J6(indicator bypass).

To enable drop lighting, short pins 2-3 of J4(Light select), to enable only per key lighting short pins 1-2 of J4. 
If you wish to use per key lighting, you also need to short pins 1-2 of 5. 

| Indicator | Drop lighting | Per key 	| j6(Ind Bypass) 	| j4(Light select) 	|j5(Backlight) 	| 
| :---: | :---: | :---: | :---: | :---: | :---: |
|  N  |  N  |  N  | |	| |
|  N  |  N  |**Y**| 1-2 | 1-2 	| |
|  N  |**Y**|  N  | 1-2 | 2-3 	| |
|  N  |**Y**|**Y**| 1-2 | 2-3	| 1-2 |
|**Y**|  N  |  N  | 2-3 |	| |
|**Y**|  N  |**Y**| 2-3 | 1-2 	| |
|**Y**|**Y**|  N  | 2-3 | 2-3 	| |
|**Y**|**Y**|**Y**| 2-3 | 2-3	| 1-2 |

The per key lighting is painful and slow. For these it is definitely best to do them in order, and test regularly. Use as low a temperature as you can manage, place the board flat on a table, and drop an led in. Create a solder bridge from the led to the board, not spending too much time with the iron on the led (few seconds) otherwise it will burn out. 

If the part of the string stops working, resolder the last working one, and the first to fail, then if needed replace them. 

#### LED Layouts 
** Indicator + drop lighting  **
LED layout underlighting
** Indicator + per key lighting  **
LED layout per key
** Indicator + drop lighting + per key lighting **
LED layout both

### Components on the backside

- Start with the diodes. Make sure you have orientation right - they are all oriented to the same side. The end with the thin line is Cathode (-) and it should go in the direction of the "arrow" symbol on the PCB.

- Sockets for switches belong again on the back side, the same side as diodes. Make sure they are flush with PCB and match the orientation shown on the silkscreen. 

### Bridge the oled pads
This is done on the top side, all 4 solder bridges must be completed. This is easier before the pro micro headers are soldered 

### Components on the front side

- Button and TRRS sockets belong to the top. Use a piece of tape to fix them and apply solder from the bottom side.

### Pro Micro and displays

- The pro micro must be installed with the components facing the pcb, and the plain back side facing out. Theoretically I think these could be installed on the under side for a lower profile. 

Make sure that you use the outlined headers from whichever side of the board that you mount the micro on. 

- Install the oled so it sits over the pro micro 

### Rotary encoders

- Add rotary encoders last, they are big, and make soldering harder 

### Keyboard switches and plates

- Mount the stand-offs to the top plate.

- Snap first switches into corners of the plate.

- Carefully snap the first switches to the sockets. Be careful so you don't bend their contacts.

- Add the rest of the switches

- Mount the bottom plate.

### Finishing touches

- Install the rotary encoder knob.

- Optionally add oled covers

- Put at least 4 adhesive rubber feet in the corners so the keyboard is not moving when you type.

## Warnings and disclaimers

- Don't connect or disconnect the TRRS cable when the keyboard is powered. It may short out. Always disconnect the USB cable first.
- Be gentle with micro USB ports on your microcontrollers. They are easy to break.
- Keep in mind that this is a prototype of a DIY keyboard. It's not a polished product.

## Firmware and programming

Sofle keyboard uses [QMK Firmware][qmk_firmware] and support for the board is part of the main QMK repository. There's also a basic support in [QMK Configurator][qmk_configurator] but there's no encoder  or led support.

Suggested approach is to build the firmware yourself. You should be familiar with QMK and be able to make it work on your local environment. If not, please [follow the instructions in the documentation][qmkintro].

- Make sure your QMK environment [is setup][qmkintro].
- Make sure halves are not connected together with TRRS cable.
- Connect one half to USB, flash the firmware (always follow the actuall instructions in the QMK documentation! The command might look something like this: `qmk flash -kb sofle/rev1 -km rgb_default`). Use the reset button to reset the keyboard when you are asked to in console. 
- Connect the second half and flash it in the same way as the previous one.
- Disconnect the USB cable. Connect both halves together with TRRS cable.
- Connect USB cable to the **left** side. 
- Enjoy SofleKeyboard!

## Troubleshooting

See the Sofle build guide.

**V2.0 Boards** - There is a known issue on V2.0 boards with the LED circuit - a trace is missing to a via on the underside of the board (on top on the left half)

Symptoms: only the first 4 underglow LEDs will work, this will occur on both halves of the board, 

Remedy: This can be easily corrected by adding a wire between the via and the trace immediately above it in the picture. You may need to scrape off the solder mask on the via depending on which manufacturer you used. 
The other end can either be attached to the trace (after removing some mask), or the footprint/led itself. 

Problem Via, In the thumb cluster on the left half of the board.

This has been corrected in the v2.1 boards, and hopefully hasn't caught too many people out. Thanks to jmo808 for finding it, and apologies once again. 

## Links

- [Github with KiCad projects][soflegithub]
- [Layout in KeyboardLayout editor][soflelayout]
- [QMK Firmware][qmk_firmware]
- [QMK Configurator][qmk_configurator]

## Firmware 

SofleRGB uses [QMK firmware](https://qmk.fm/), it can use any Sofle keymap. 

## Default layout 

The default layout for the SofleRGB is in the qmk repo, and demonstrates some LED functions. 

Default layout for SofleRGB Keyboard

## Images of keyboard

SofleRGBKeyboard

SofleRGBKeyboard

SofleRGBKeyboard PCB

## Footnotes
[layoutarticle]: <https://josef-adamcik.cz/electronics/in-search-of-the-best-custom-keyboard-layout.html> "In search of the best custom keyboard layout"
[introductionarticle]: <https://josef-adamcik.cz/electronics/let-me-introduce-you-sofle-keyboard-split-keyboard-based-on-lily58.html> "Let me introduce you SofleKeyboard - a split keyboard based on Lily58 and Crkbd"
[soflelayout]: http://www.keyboard-layout-editor.com/#/gists/76efb423a46cbbea75465cb468eef7ff "Sofle Keyboard layout at keyboard-layout-editor.com"
[soflegerber]: https://github.com/josefadamcik/SofleKeyboard/releases "SofleKeyboard - gerber files"
[qmk_firmware]: https://github.com/qmk/qmk_firmware/ "QMK firmware"

[qmk_configurator]: https://config.qmk.fm/#/sofle/rev1/LAYOUT "QMK configurator"
[springpinheader]: <https://yushakobo.jp/shop/a01mc-00/> "Spring pin headers - Japaneese"
[qmkprotonc]: https://qmk.fm/proton-c/ "QMK Proton-C"
[promicrosocketing]: <https://docs.splitkb.com/hc/en-us/articles/360011263059> "How do I socket a microcontroller? by splitkb.com"
[qmkintro]: <https://beta.docs.qmk.fm/newbs/newbs_getting_started> "QMK getting started"
[qmkhandedness]: <https://docs.qmk.fm/#/feature_split_keyboard?id=setting-handedness> "QMK firmware - setting handedness"
[manufacturingproblems]: https://josef-adamcik.cz/electronics/corne-keyboard-build-log.html#manufacturing-at-jlcpcb---update-27112019 "Possible problems when manufacturing top plate for Corne"
[nooledlag]: https://github.com/qmk/qmk_firmware/issues/7522 "No OLED lag bug"
[soflegithub]: https://github.com/josefadamcik/SofleKeyboard "SofleKeyboard - KiCad project on Github.com"
[sourcing]: <{{ site.baseurl }}/sourcing_parts.html> "Sourcing parts"
[keyhivebuildguide]: <https://github.com/keyhive/build_guides/blob/master/docs/keyboards/sofle-rgb.md> "Sofle RGB Keyhive build guide"
[buildguide]: <{{ site.baseurl }}/build_guide.html> "Sofle V1/V2 build guide"

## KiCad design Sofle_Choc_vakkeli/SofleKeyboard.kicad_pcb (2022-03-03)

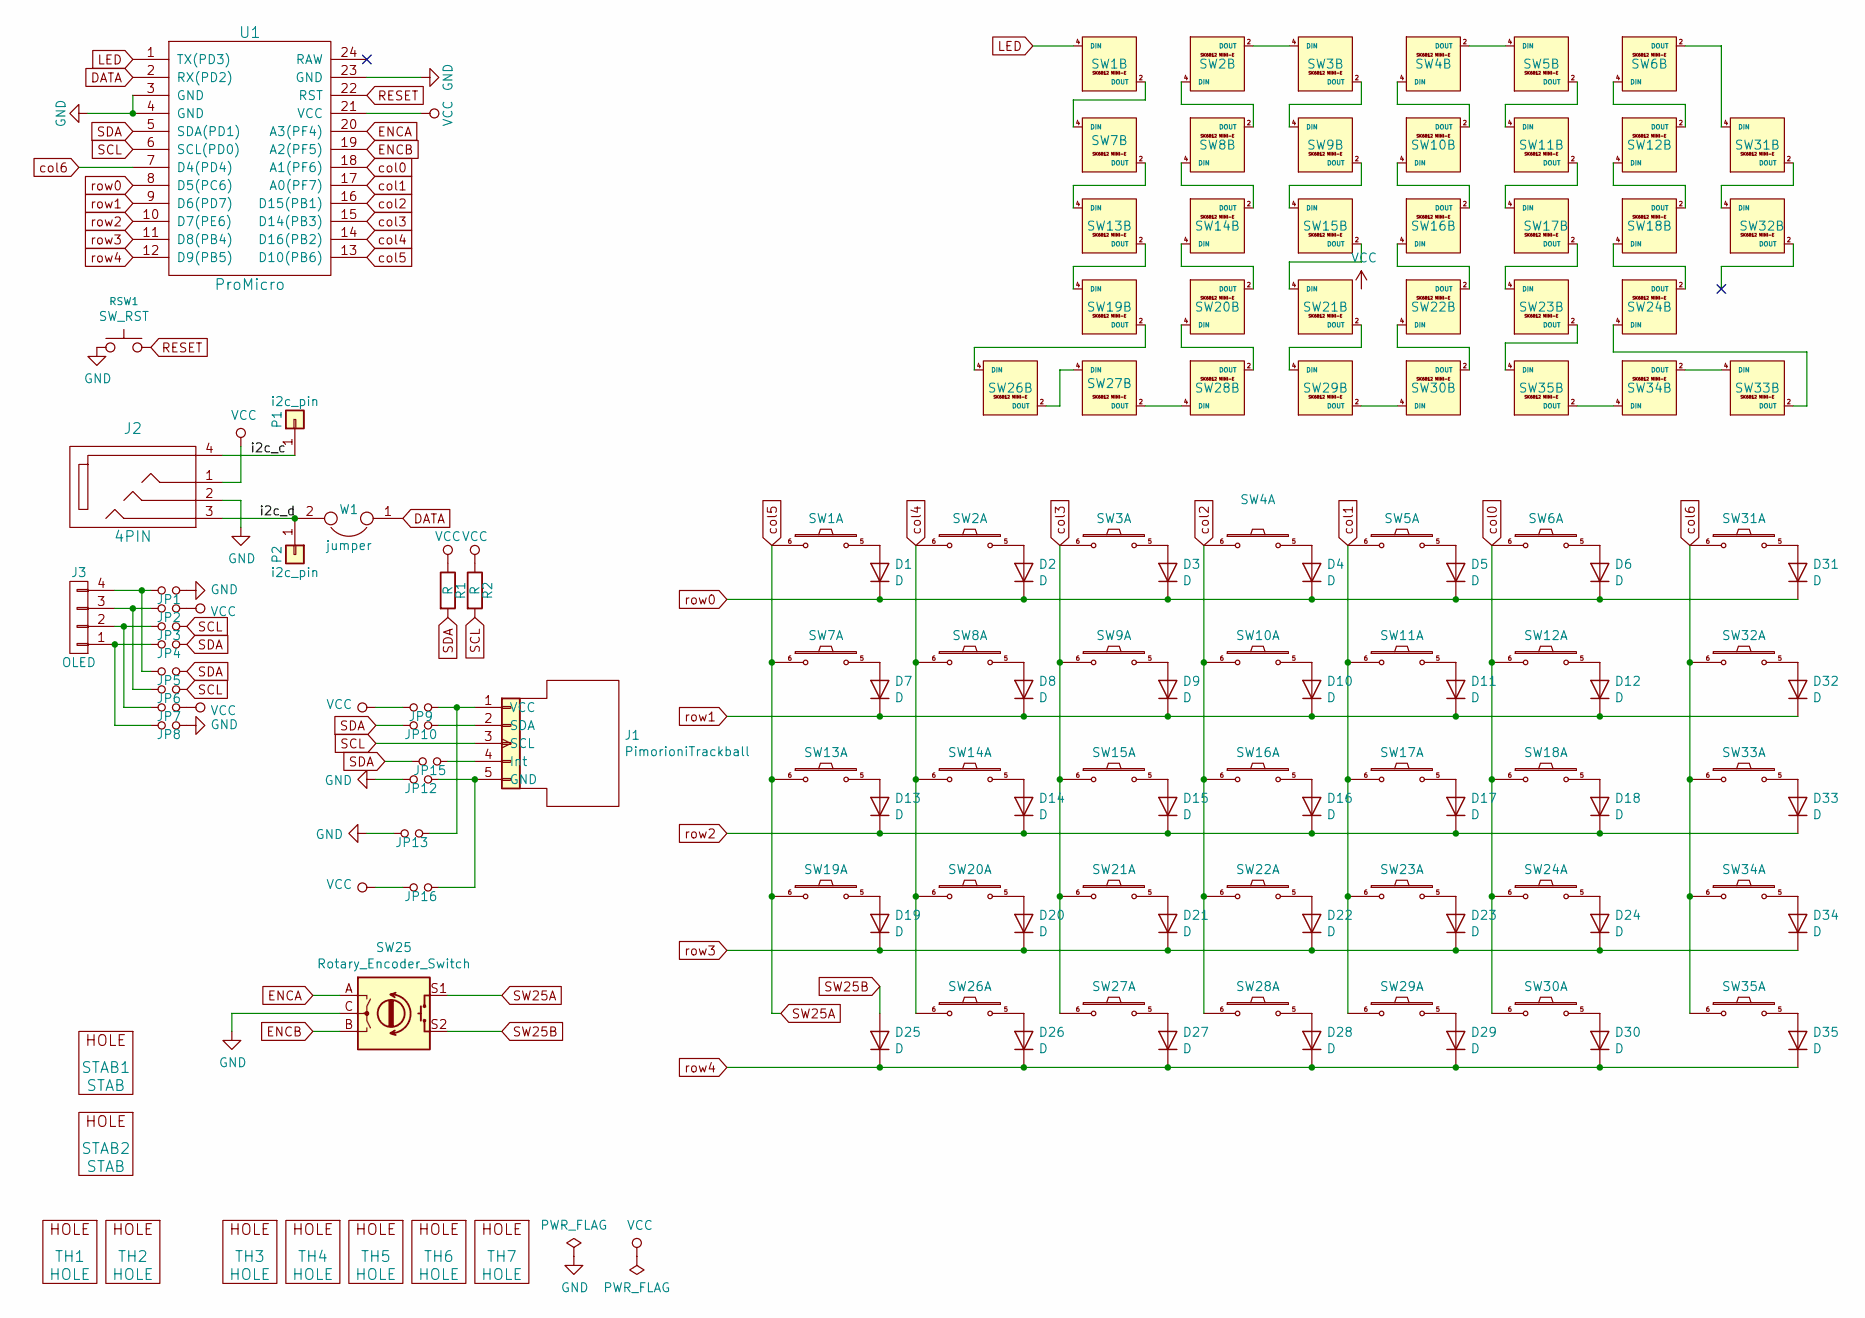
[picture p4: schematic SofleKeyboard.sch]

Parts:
D1, D2, D3, D4, D5, D6, D7, D8, D9, D10, D11, D12, D13, D14, D15, D16, D17, D18, D19, D20, D21, D22, D23, D24, D25, D26, D27, D28, D29, D30, D31, D32, D33, D34, D35: D; crkbd-diode
J1: PimorioniTrackball; pimoroni_trackball
J2: 4PIN; MJ-4PP-9
J3: OLED; OLED_4Pin
JP1, JP2, JP3, JP4, JP5, JP6, JP7, JP8, JP9, JP10, JP12, JP13, JP15, JP16: Jumper_NO_Small; Jumper
P1, P2: i2c_pin; 1pin_conn
R1, R2: R; RESISTOR_mini
RSW1: SW_RST; TACT_SWITCH_TVBP06
STAB1, STAB2: STAB; Kailh-PG1350-2u-stab
SW1, SW2, SW3, SW4, SW5, SW6, SW7, SW8, SW9, SW10, SW11, SW12, SW13, SW14, SW15, SW16, SW17, SW18, SW19, SW20, SW21, SW22, SW23, SW24, SW26, SW27, SW28, SW29, SW30, SW31, SW32, SW33, SW34, SW35: SW_PUSH_LED; Choc_Hotswap_SK6812MiniE
SW25: Rotary_Encoder_Switch; RotaryEncoder_Alps_EC11E-Switch_Vertical_H20mm-keebio_modif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
TH1, TH2: HOLE; M2_HOLE_PCB
TH3, TH4, TH5, TH6, TH7: HOLE; HOLE_M2_TH
U1: ProMicro
W1: jumper; jumper_data

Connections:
/i2c_c: J2.4, P1.1
/i2c_d: J2.3, P2.1, W1.2
DATA: U1.2 (RX(PD2)), W1.1
ENCA: SW3.C, SW25.A, U1.20 (A3(PF4))
ENCB: SW3.B, SW25.B, U1.19 (A2(PF5))
GND: J2.2, JP1.2, JP8.2, JP12.1, JP13.1, RSW1.1, SW1.3 (GND), SW2.3 (GND), SW3.A, SW4.3 (GND), SW5.3 (GND), SW6.3 (GND), SW7.3 (GND), SW8.3 (GND), SW9.3 (GND), SW10.3 (GND), SW11.3 (GND), SW12.3 (GND), SW13.3 (GND), SW14.3 (GND), SW15.3 (GND), SW16.3 (GND), SW17.3 (GND), SW18.3 (GND), SW19.3 (GND), SW20.3 (GND), SW21.3 (GND), SW22.3 (GND), SW23.3 (GND), SW24.3 (GND), SW25.C, SW26.3 (GND), SW27.3 (GND), SW28.3 (GND), SW29.3 (GND), SW30.3 (GND), SW31.3 (GND), SW32.3 (GND), SW33.3 (GND), SW34.3 (GND), SW35.3 (GND), U1.3 (GND), U1.4 (GND), U1.23 (GND); also elsewhere on the board
LED: SW1.4 (DIN), U1.1 (TX(PD3))
unnamed: D1.2 (A), SW1.5
unnamed: D2.2 (A), SW2.5
unnamed 9: D3.2 (A), SW3.5; also elsewhere on the board
unnamed: D4.2 (A), SW4.5
unnamed: D5.2 (A), SW5.5
unnamed: D6.2 (A), SW6.5
unnamed: D7.2 (A), SW7.5
unnamed: D8.2 (A), SW8.5
unnamed: D9.2 (A), SW9.5
unnamed: D10.2 (A), SW10.5
unnamed: D11.2 (A), SW11.5
unnamed: D12.2 (A), SW12.5
unnamed: D13.2 (A), SW13.5
unnamed: D14.2 (A), SW14.5
unnamed: D15.2 (A), SW15.5
unnamed: D16.2 (A), SW16.5
unnamed: D17.2 (A), SW17.5
unnamed: D18.2 (A), SW18.5
unnamed: D19.2 (A), SW19.5
unnamed: D20.2 (A), SW20.5
unnamed: D21.2 (A), SW21.5
unnamed: D22.2 (A), SW22.5
unnamed: D23.2 (A), SW23.5
unnamed: D24.2 (A), SW24.5
unnamed: D26.2 (A), SW26.5
unnamed: D27.2 (A), SW27.5
unnamed: D28.2 (A), SW28.5
unnamed: D29.2 (A), SW29.5
unnamed: D30.2 (A), SW30.5
unnamed: D31.2 (A), SW31.5
unnamed: D32.2 (A), SW32.5
unnamed: D33.2 (A), SW33.5
unnamed: D34.2 (A), SW34.5
unnamed: D35.2 (A), SW35.5
unnamed: J1.1 (VCC), JP9.2, JP13.2
unnamed: J1.2 (SDA), JP10.2
unnamed: J1.4 (Int), JP15.2
unnamed: J1.5 (GND), JP12.2, JP16.2
unnamed: J3.1, JP4.1, JP8.1
unnamed: J3.2, JP3.1, JP7.1
unnamed: J3.3, JP2.1, JP6.1
unnamed: J3.4, JP1.1, JP5.1
unnamed: SW1.2 (DOUT), SW7.4 (DIN)
unnamed 50: SW2.2 (DOUT), SW3.4 (DIN); also elsewhere on the board
unnamed: SW2.4 (DIN), SW8.2 (DOUT)
unnamed 52: SW3.2 (DOUT), SW9.4 (DIN); also elsewhere on the board
unnamed: SW4.2 (DOUT), SW5.4 (DIN)
unnamed: SW4.4 (DIN), SW10.2 (DOUT)
unnamed: SW10.4 (DIN), SW16.2 (DOUT)
unnamed: SW11.2 (DOUT), SW17.4 (DIN)
unnamed: SW5.2 (DOUT), SW11.4 (DIN)
unnamed: SW6.4 (DIN), SW12.2 (DOUT)
unnamed: SW12.4 (DIN), SW18.2 (DOUT)
unnamed: SW13.2 (DOUT), SW19.4 (DIN)
unnamed: SW7.2 (DOUT), SW13.4 (DIN)
unnamed: SW8.4 (DIN), SW14.2 (DOUT)
unnamed: SW14.4 (DIN), SW20.2 (DOUT)
unnamed: SW15.2 (DOUT), SW21.4 (DIN)
unnamed: SW9.2 (DOUT), SW15.4 (DIN)
unnamed: SW16.4 (DIN), SW22.2 (DOUT)
unnamed: SW17.2 (DOUT), SW23.4 (DIN)
unnamed: SW18.4 (DIN), SW24.2 (DOUT)
unnamed: SW19.2 (DOUT), SW26.4 (DIN)
unnamed: SW20.4 (DIN), SW28.2 (DOUT)
unnamed: SW21.2 (DOUT), SW29.4 (DIN)
unnamed: SW22.4 (DIN), SW30.2 (DOUT)
unnamed: SW23.2 (DOUT), SW35.4 (DIN)
unnamed: SW24.4 (DIN), SW33.2 (DOUT)
unnamed: SW26.2 (DOUT), SW27.4 (DIN)
unnamed: SW27.2 (DOUT), SW28.4 (DIN)
unnamed: SW29.2 (DOUT), SW30.4 (DIN)
unnamed: SW31.2 (DOUT), SW32.4 (DIN)
unnamed: SW6.2 (DOUT), SW31.4 (DIN)
unnamed: SW33.4 (DIN), SW34.2 (DOUT)
unnamed: SW34.4 (DIN), SW35.2 (DOUT)
RESET: RSW1.2, U1.22 (RST)
SCL: J1.3 (SCL), JP3.2, JP6.2, R2.2, U1.6 (SCL(PD0))
SDA: JP4.2, JP5.2, JP10.1, JP15.1, R1.2, U1.5 (SDA(PD1))
SW25A: SW1.6, SW3.S1, SW7.6, SW13.6, SW19.6, SW25.S1, U1.13 (D10(PB6))
SW25B: D25.2 (A), SW3.S2, SW25.S2
VCC: J2.1, JP2.2, JP7.2, JP9.1, JP16.1, R1.1, R2.1, SW1.1 (VDD), SW2.1 (VDD), SW4.1 (VDD), SW5.1 (VDD), SW6.1 (VDD), SW7.1 (VDD), SW8.1 (VDD), SW9.1 (VDD), SW10.1 (VDD), SW11.1 (VDD), SW12.1 (VDD), SW13.1 (VDD), SW14.1 (VDD), SW15.1 (VDD), SW16.1 (VDD), SW17.1 (VDD), SW18.1 (VDD), SW19.1 (VDD), SW20.1 (VDD), SW21.1 (VDD), SW22.1 (VDD), SW23.1 (VDD), SW24.1 (VDD), SW26.1 (VDD), SW27.1 (VDD), SW28.1 (VDD), SW29.1 (VDD), SW30.1 (VDD), SW31.1 (VDD), SW32.1 (VDD), SW33.1 (VDD), SW34.1 (VDD), SW35.1 (VDD), U1.21 (VCC); also elsewhere on the board
col0: SW6.6, SW12.6, SW18.6, SW24.6, SW30.6, U1.18 (A1(PF6))
col1: SW5.6, SW11.6, SW17.6, SW23.6, SW29.6, U1.17 (A0(PF7))
col2: SW4.6, SW10.6, SW16.6, SW22.6, SW28.6, U1.16 (D15(PB1))
col3: SW3.6, SW9.6, SW15.6, SW21.6, SW27.6, U1.15 (D14(PB3)); also elsewhere on the board
col4: SW2.6, SW8.6, SW14.6, SW20.6, SW26.6, U1.14 (D16(PB2))
col6: SW31.6, SW32.6, SW33.6, SW34.6, SW35.6, U1.7 (D4(PD4))
row0: D1.1 (K), D2.1 (K), D3.1 (K), D4.1 (K), D5.1 (K), D6.1 (K), D31.1 (K), U1.8 (D5(PC6))
row1: D7.1 (K), D8.1 (K), D9.1 (K), D10.1 (K), D11.1 (K), D12.1 (K), D32.1 (K), U1.9 (D6(PD7))
row2: D13.1 (K), D14.1 (K), D15.1 (K), D16.1 (K), D17.1 (K), D18.1 (K), D33.1 (K), U1.10 (D7(PE6))
row3: D19.1 (K), D20.1 (K), D21.1 (K), D22.1 (K), D23.1 (K), D24.1 (K), D34.1 (K), U1.11 (D8(PB4))
row4: D25.1 (K), D26.1 (K), D27.1 (K), D28.1 (K), D29.1 (K), D30.1 (K), D35.1 (K), U1.12 (D9(PB5))

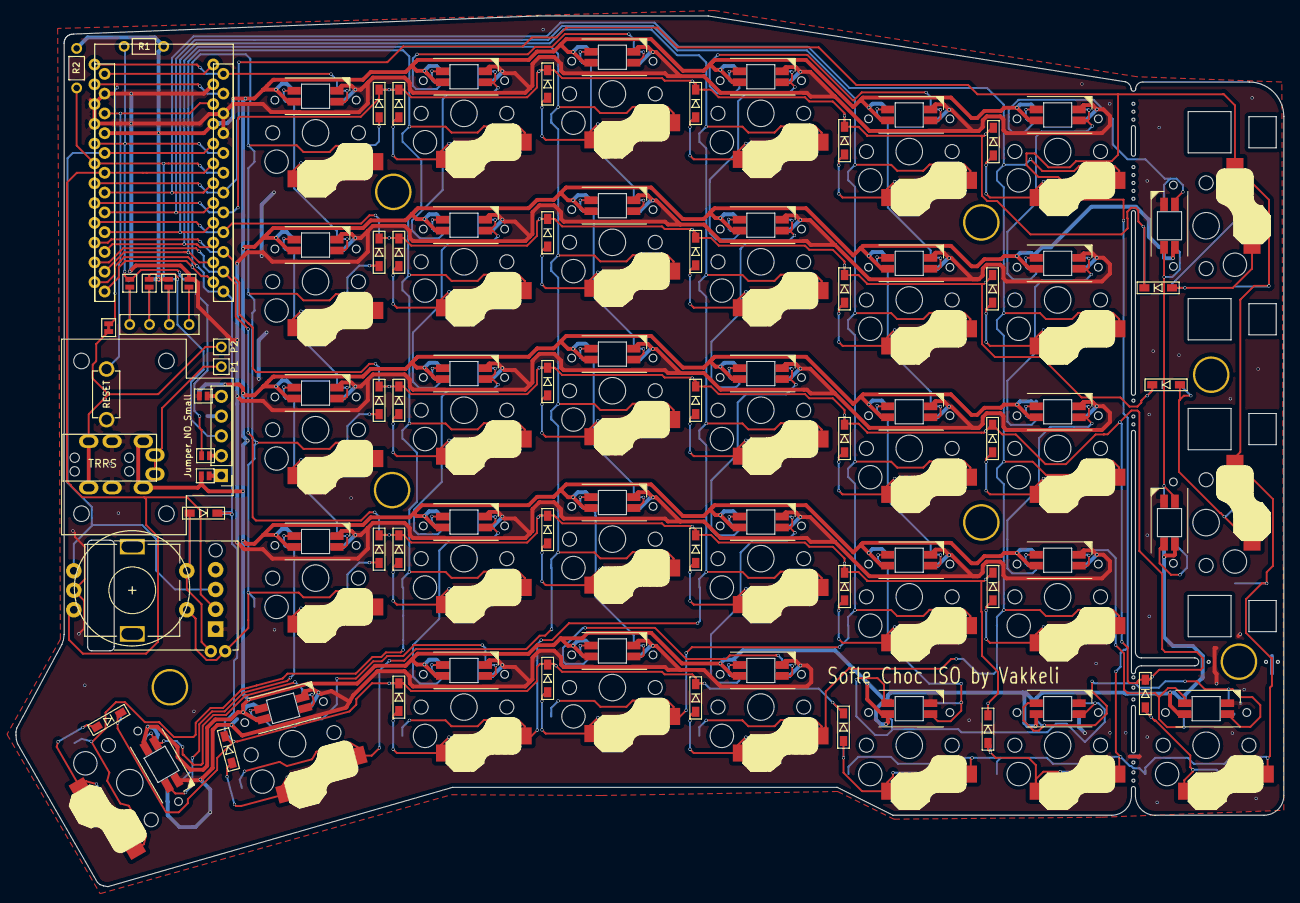
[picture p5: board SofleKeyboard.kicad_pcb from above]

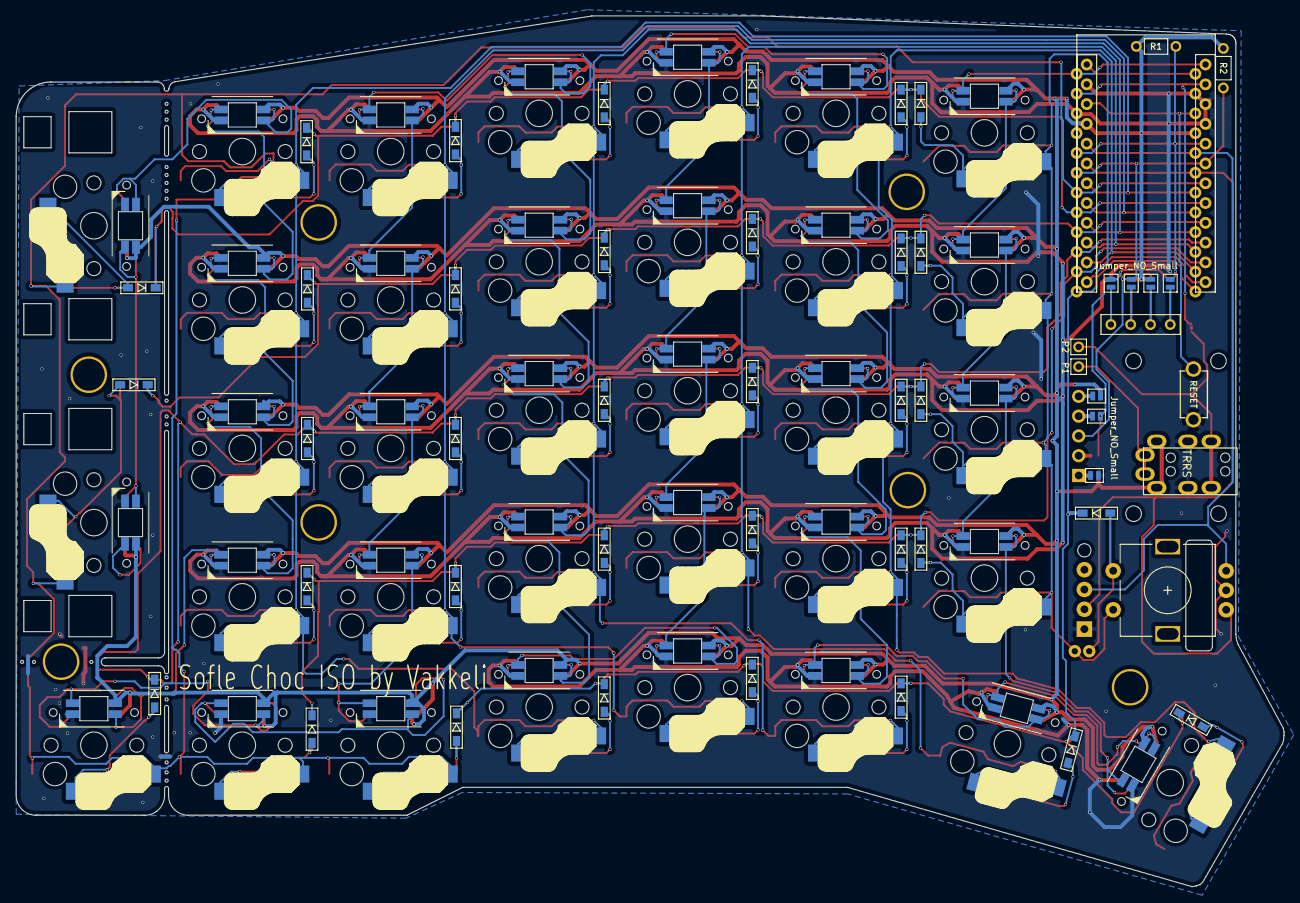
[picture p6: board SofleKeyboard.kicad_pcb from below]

Board: 2 copper layers, 162.7 x 111.8 mm, 104 parts (7 on the bottom side), 99 nets.

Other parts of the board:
SW3#2: SW_PUSH_LED; Choc_Hotswap_SK6812MiniE
TH6#2, TH6#3: HOLE; HOLE_M2_TH

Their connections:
GND: SW3#2.3; also elsewhere on the board
unnamed 9: SW3#2.5; also elsewhere on the board
unnamed 50: SW3#2.4; also elsewhere on the board
unnamed 52: SW3#2.2; also elsewhere on the board
VCC: SW3#2.1; also elsewhere on the board
col3: SW3#2.6; also elsewhere on the board

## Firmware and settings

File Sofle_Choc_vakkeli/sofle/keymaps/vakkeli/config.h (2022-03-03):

 /* Copyright 2021 Dane Evans
  *
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
  * You should have received a copy of the GNU General Public License
  * along with this program.  If not, see <http://www.gnu.org/licenses/>.
*/
  #pragma once


//#define USE_MATRIX_I2C

/* Select hand configuration */

///https://thomasbaart.nl/2018/12/01/reducing-firmware-size-in-qmk/


#define MASTER_LEFT
// #define MASTER_RIGHT
// #define EE_HANDS

#define CUSTOM_FONT

#define CUSTOM_LAYER_READ //if you remove this it causes issues - needs better guarding


#define TAPPING_FORCE_HOLD
#ifdef TAPPING_TERM
    #undef TAPPING_TERM
    #define TAPPING_TERM 200
#endif
#define ENCODER_DIRECTION_FLIP


#define RGBLIGHT_SLEEP
//
#define RGBLIGHT_LAYERS

/* ws2812 RGB LED */
#define RGB_DI_PIN D3

#ifdef RGB_MATRIX_ENABLE
#define RGBLED_NUM 35    // Number of LEDs
#define RGBLED_NUM 35    // Number of LEDs
#define RGB_MATRIX_SPLIT { 34, 34 }
#endif

#ifdef RGBLIGHT_ENABLE
    #undef RGBLED_NUM

    //#define RGBLIGHT_ANIMATIONS
	//#define RGBLIGHT_EFFECT_BREATHING
	// #define RGBLIGHT_EFFECT_RAINBOW_MOOD
	//#define RGBLIGHT_EFFECT_RAINBOW_SWIRL
	//#define RGBLIGHT_EFFECT_SNAKE
	//#define RGBLIGHT_EFFECT_KNIGHT
	//#define RGBLIGHT_EFFECT_CHRISTMAS
	//#define RGBLIGHT_EFFECT_STATIC_GRADIENT
	//#define RGBLIGHT_EFFECT_RGB_TEST
	//#define RGBLIGHT_EFFECT_ALTERNATING
	//#define RGBLIGHT_EFFECT_TWINKLE

    #define RGBLED_NUM 70
	//#define RGBLED_SPLIT
	#define RGBLED_SPLIT { 35, 35 } // haven't figured out how to use this yet

	//#define RGBLED_NUM 30
    #define RGBLIGHT_LIMIT_VAL 120
    #define RGBLIGHT_HUE_STEP 10
    #define RGBLIGHT_SAT_STEP 17
    #define RGBLIGHT_VAL_STEP 17
#endif

#ifdef RGB_MATRIX_ENABLE
// #   define RGB_MATRIX_KEYPRESSES // reacts to keypresses
// #   define RGB_MATRIX_KEYRELEASES // reacts to keyreleases (instead of keypresses)
#   define RGB_DISABLE_AFTER_TIMEOUT 60 // number of ticks to wait until disabling effects
#   define RGB_DISABLE_WHEN_USB_SUSPENDED // turn off effects when suspended
#   define RGB_MATRIX_FRAMEBUFFER_EFFECTS
// #   define RGB_MATRIX_LED_PROCESS_LIMIT (DRIVER_LED_TOTAL + 4) / 5 // limits the number of LEDs to process in an animation per task run (increases keyboard responsiveness)
#   define RGB_MATRIX_LED_FLUSH_LIMIT 16 // limits in milliseconds how frequently an animation will update the LEDs. 16 (16ms) is equivalent to limiting to 60fps (increases keyboard responsiveness)
#    define RGB_MATRIX_MAXIMUM_BRIGHTNESS 150 // limits maximum brightness of LEDs to 150 out of 255. Higher may cause the controller to crash.

// #define RGB_MATRIX_STARTUP_MODE RGB_MATRIX_GRADIENT_LEFT_RIGHT

#    define RGB_MATRIX_HUE_STEP 25
#    define RGB_MATRIX_SAT_STEP 25
#    define RGB_MATRIX_VAL_STEP 25
#    define RGB_MATRIX_SPD_STEP 10

// #define ENABLE_RGB_MATRIX_ALPHAS_MODS	//Enables RGB_MATRIX_ALPHAS_MODS
// #define ENABLE_RGB_MATRIX_GRADIENT_UP_DOWN	//Enables RGB_MATRIX_GRADIENT_UP_DOWN

// #define ENABLE_RGB_MATRIX_GRADIENT_LEFT_RIGHT
// #define ENABLE_RGB_MATRIX_RAINBOW_MOVING_CHEVRON

// #define ENABLE_RGB_MATRIX_BREATHING

/* Disable the animations you don't want/need.  You will need to disable a good number of these    *
 * because they take up a lot of space.  Disable until you can successfully compile your firmware. */
 // #   undef ENABLE_RGB_MATRIX_ALPHAS_MODS
 // #define ENABLE_RGB_MATRIX_GRADIENT_UP_DOWN
 // #   undef ENABLE_RGB_MATRIX_BREATHING
 // #   undef ENABLE_RGB_MATRIX_CYCLE_ALL
 // #   undef ENABLE_RGB_MATRIX_CYCLE_LEFT_RIGHT
 // #   undef ENABLE_RGB_MATRIX_CYCLE_UP_DOWN
 // #   undef ENABLE_RGB_MATRIX_CYCLE_OUT_IN
 // #   undef ENABLE_RGB_MATRIX_CYCLE_OUT_IN_DUAL
 // #   undef ENABLE_RGB_MATRIX_RAINBOW_MOVING_CHEVRON
 // #   undef ENABLE_RGB_MATRIX_DUAL_BEACON
 // #   undef ENABLE_RGB_MATRIX_RAINBOW_BEACON
 // #   undef ENABLE_RGB_MATRIX_RAINBOW_PINWHEELS
 // #   undef ENABLE_RGB_MATRIX_RAINDROPS
 // #   undef ENABLE_RGB_MATRIX_JELLYBEAN_RAINDROPS
 // #   undef ENABLE_RGB_MATRIX_TYPING_HEATMAP
 // #   undef ENABLE_RGB_MATRIX_DIGITAL_RAIN
 // #   undef ENABLE_RGB_MATRIX_SOLID_REACTIVE
 // #   undef ENABLE_RGB_MATRIX_SOLID_REACTIVE_SIMPLE
 // #   undef ENABLE_RGB_MATRIX_SOLID_REACTIVE_WIDE
 // #   undef ENABLE_RGB_MATRIX_SOLID_REACTIVE_MULTIWIDE
 // #   undef ENABLE_RGB_MATRIX_SOLID_REACTIVE_CROSS
 // #   undef ENABLE_RGB_MATRIX_SOLID_REACTIVE_MULTICROSS
 // #   undef ENABLE_RGB_MATRIX_SOLID_REACTIVE_NEXUS
 // #   undef ENABLE_RGB_MATRIX_SOLID_REACTIVE_MULTINEXUS
 // #   undef ENABLE_RGB_MATRIX_SPLASH
 // #   undef ENABLE_RGB_MATRIX_MULTISPLASH
 // #   undef ENABLE_RGB_MATRIX_SOLID_SPLASH
 // #   undef ENABLE_RGB_MATRIX_SOLID_MULTISPLASH

 #    define DISABLE_RGB_MATRIX_ALPHAS_MODS
#    define DISABLE_RGB_MATRIX_GRADIENT_UP_DOWN
#    define DISABLE_RGB_MATRIX_BREATHING
#    define DISABLE_RGB_MATRIX_BAND_SAT
#    define DISABLE_RGB_MATRIX_BAND_VAL
#    define DISABLE_RGB_MATRIX_BAND_PINWHEEL_SAT
#    define DISABLE_RGB_MATRIX_BAND_PINWHEEL_VAL
#    define DISABLE_RGB_MATRIX_BAND_SPIRAL_SAT
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

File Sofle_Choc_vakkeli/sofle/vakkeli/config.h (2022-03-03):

#pragma once

/* USB Device descriptor parameter */
#define VENDOR_ID       0xFC32
#define PRODUCT_ID      0x0287
#define DEVICE_VER      0x0002
#define MANUFACTURER    Vakkeli
#define PRODUCT         Sofle

// The pin connected to the data pin of the LEDs
#define RGB_DI_PIN D3
// The number of LEDs connected
#define DRIVER_LED_TOTAL 68

/* key matrix size */
// Rows are doubled-up
#define MATRIX_ROWS 10
#define MATRIX_COLS 7

// wiring of each half
#define MATRIX_ROW_PINS { C6, D7, E6, B4, B5 }
#define MATRIX_COL_PINS { F6, F7, B1, B3, B2, B6, D4}
#define DIODE_DIRECTION COL2ROW

#define TAPPING_TERM 100
#define DEBOUNCE 5

/* encoder support */
#define ENCODERS_PAD_A { F5 }
#define ENCODERS_PAD_B { F4 }
#define ENCODERS_PAD_A_RIGHT { F4 }
#define ENCODERS_PAD_B_RIGHT { F5 }
#define ENCODER_RESOLUTION 2

#define TAP_CODE_DELAY 10

/* communication between sides */
#define USE_SERIAL
#define SERIAL_USE_MULTI_TRANSACTION
#define SOFT_SERIAL_PIN D2

#define NO_ACTION_MACRO
#define NO_ACTION_FUNCTION
//
// #define SPLIT_WPM_ENABLE
// #define SPLIT_OLED_ENABLE

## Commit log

2022-01-18 First version of mod
    [SofleKeyboard-B_Cu.gbl, SofleKeyboard-B_Mask.gbs, SofleKeyboard-B_SilkS.gbo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]
2022-01-18 fixes, stabs, breakaways
    [SofleKeyboard-B_Cu.gbl, SofleKeyboard-B_Mask.gbs, SofleKeyboard-B_SilkS.gbo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]
2022-02-08 fixed single breakable button gnd, added dxf for 3d.
    [SofleKeyboard-B_Mask.dxf, SofleKeyboard-B_SilkS.dxf, SofleKeyboard-Edge_Cuts.dxf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]
2022-02-08 fixed single button led order
    [SofleKeyboard-B_Mask.dxf, SofleKeyboard-B_SilkS.dxf, SofleKeyboard-Edge_Cuts.dxf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]
2022-03-03 Fixes to pcb. Added functioning, but incomplete fw
    [SofleKeyboard.kicad_pcb]

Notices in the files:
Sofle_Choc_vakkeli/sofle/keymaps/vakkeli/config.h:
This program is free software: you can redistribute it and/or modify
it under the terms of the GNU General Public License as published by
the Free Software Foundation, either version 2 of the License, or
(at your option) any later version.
